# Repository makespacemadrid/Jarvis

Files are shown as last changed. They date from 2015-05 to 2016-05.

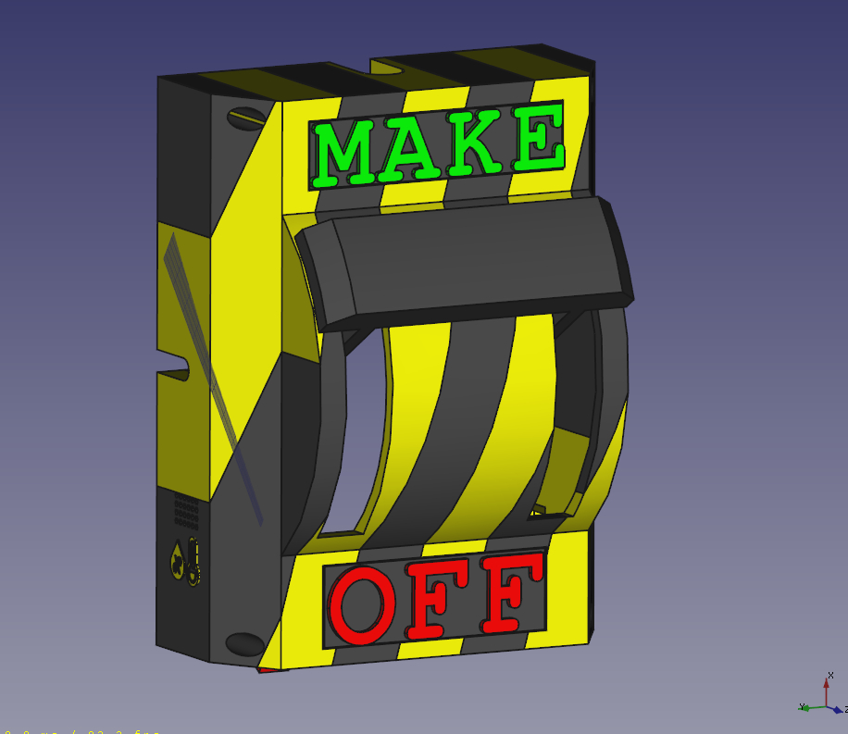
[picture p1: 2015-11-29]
Diseños3D/MakeSwitch/v2.jpg

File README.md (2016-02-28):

# Jarvis
Jarvis (En homenaje al personaje de Marvel) es un proyecto creado por los usuarios de Makespace Madrid para domotizar y automatizar distintos aspectos de dicho espacio.

Se basa en un diseño modular que permite hacerlo escalable, de forma que inicialmente será un diseño simple destinado a realizar tareas rutinarias y monótonas del local (apagado de luces, apagado de ordenadores, control y monitorización de la calidad del aire...) y poco a poco podrá ampliarse a tareas cada vez más sofisticadas y complejas.

Pese a estar siendo desarrollado para un lugar concreto es fácilmente portable a otro tipo de ambientes (locales de trabajo, viviendas... )

****Cómo colaborar:****

1- Haz un fork del repo y aprende a usar git a nivel basico:

    https://github.com/makespacemadrid/Jarvis/wiki/Git-b%C3%A1sico

2- Monta el entorno de desarollo

    https://github.com/makespacemadrid/Jarvis/wiki/Montando-el-entorno-de-desarrollo

3- Si en el camino encuentras algo que falta o esta mal explicado mejoralo en la wiki para el proximo ;)

4-Echa un ojo a los issues y encuentra alguna tarea con la que te gustaria colaborar:

    https://github.com/makespacemadrid/Jarvis/issues

5-Pásate por MakeSpace y habla con un miembro del equipo de Jarvis para tutela/materiales, el Jueves suele ser un dia propicio.

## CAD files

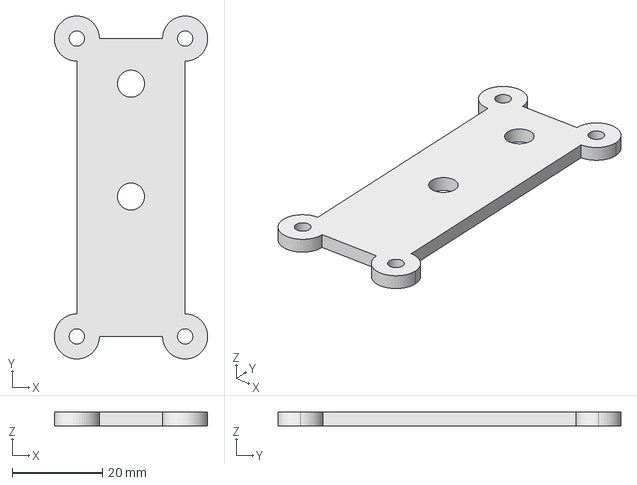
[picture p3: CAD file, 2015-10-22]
Diseños3D/CalidadAmbiental/FreeCAD/tapa_modulo.fcstd
34.0 x 76.0 x 3.00 mm

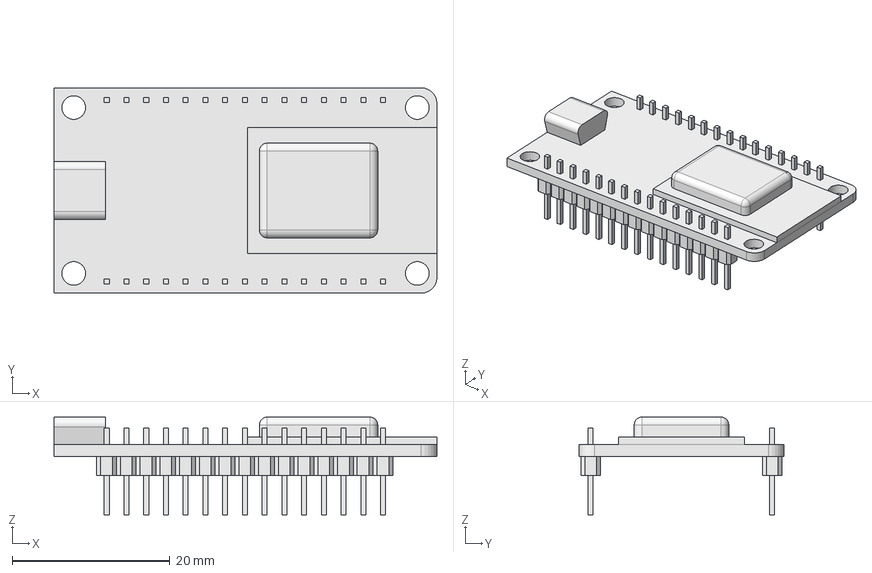
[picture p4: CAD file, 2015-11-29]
Diseños3D/esp/nodemcu.fcstd
48.5 x 26.0 x 12.4 mm
Sketch001_Extrude
NodeMCU-Compound
NodeMCU

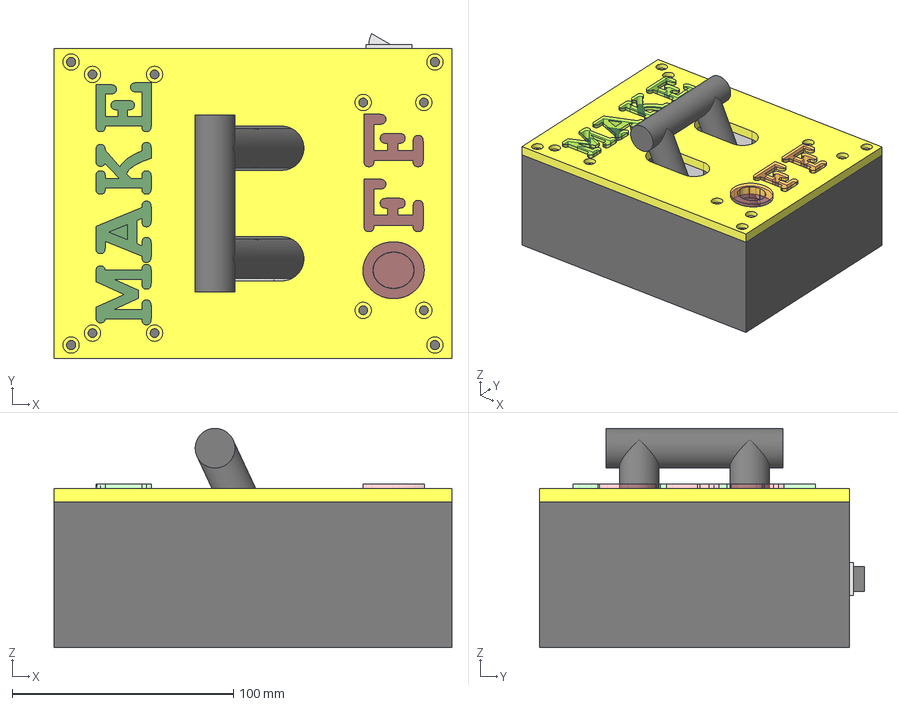
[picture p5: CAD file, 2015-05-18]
Diseños3D/MakeSwitch/FreeCad/MakeSwitch.fcstd
180.0 x 146.8 x 99.2 mm
Clone of Pad002
Clone of Pad001
Clone of Cut003
Facebinder
Interruptor003

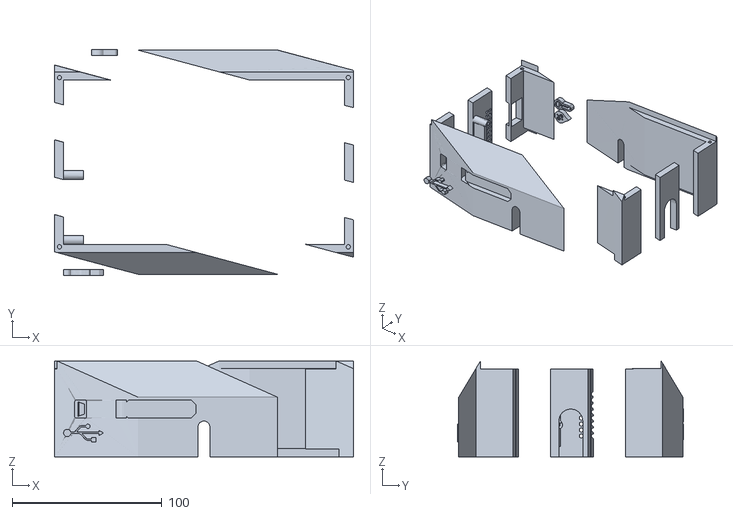
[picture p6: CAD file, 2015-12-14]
Diseños3D/MakeSwitch/FreeCad/STL/DualColor/carcasa-mitades/bottom-a (repaired).stl
200.0 x 151.3 x 64.2

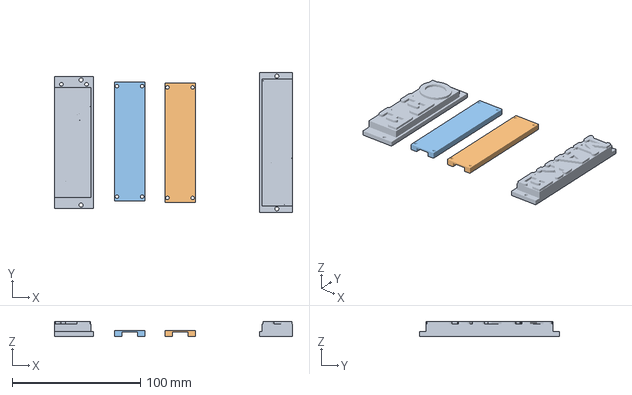
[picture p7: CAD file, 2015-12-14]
Diseños3D/MakeSwitch/FreeCad/STL/DualColor/letras-OpacoA-TransparenteB.amf
185.4 x 108.9 x 12.0 mm

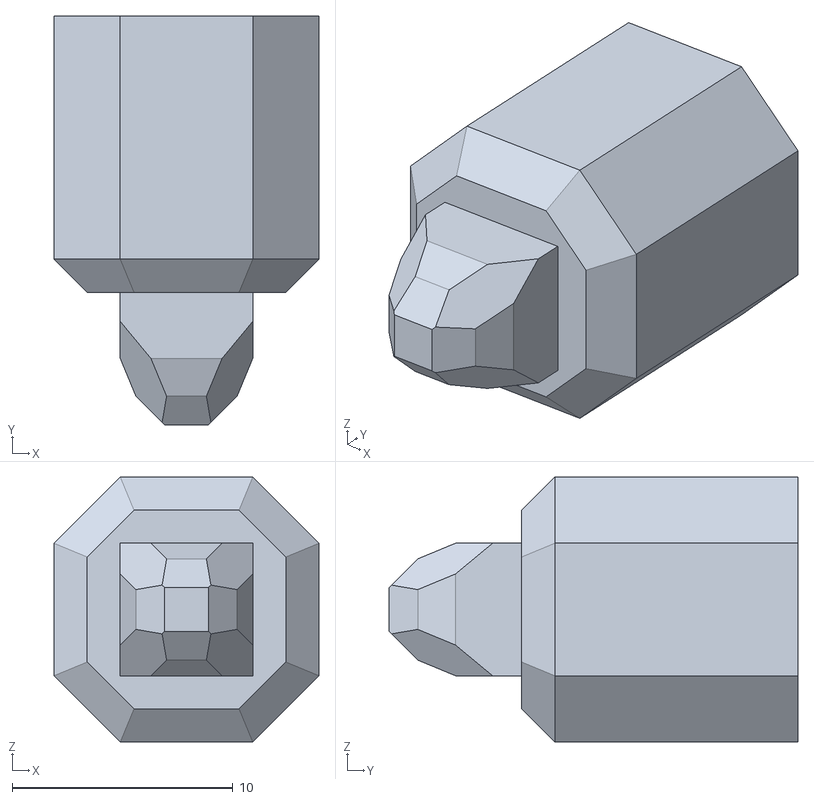
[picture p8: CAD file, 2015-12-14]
Diseños3D/MakeSwitch/FreeCad/STL/piloto.obj
12.0 x 18.5 x 12.0

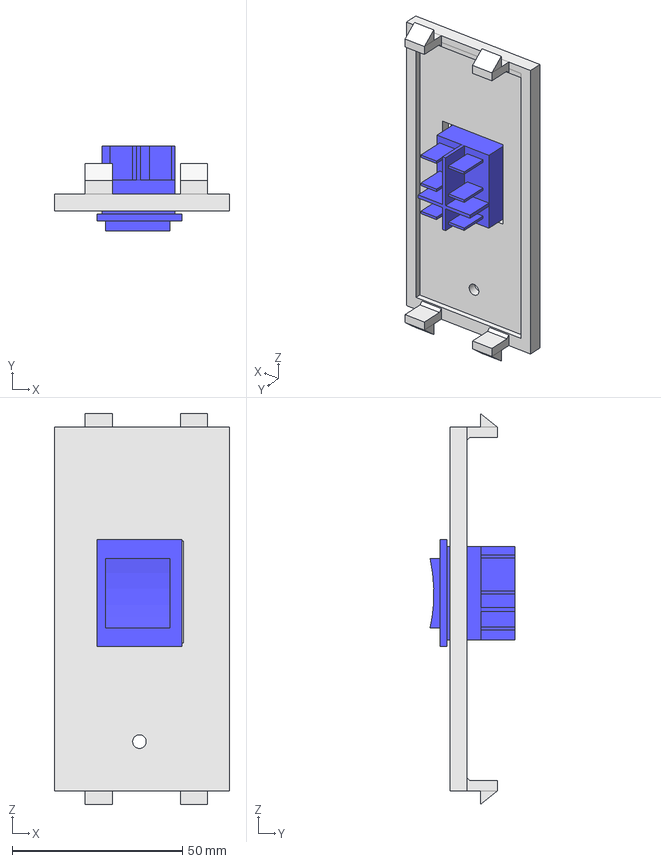
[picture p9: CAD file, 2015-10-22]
Diseños3D/Modulo para CimaBox/FreeCAD/cubre-modulos.fcstd
51.5 x 25.0 x 115.0 mm
Clone conmutador

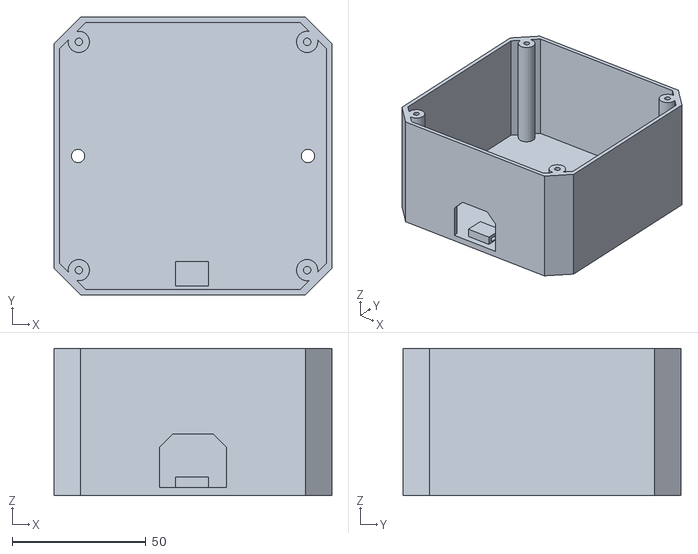
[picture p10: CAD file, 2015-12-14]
Modulos/ZonaHerramientas/caja.stl
104.0 x 104.0 x 55.0

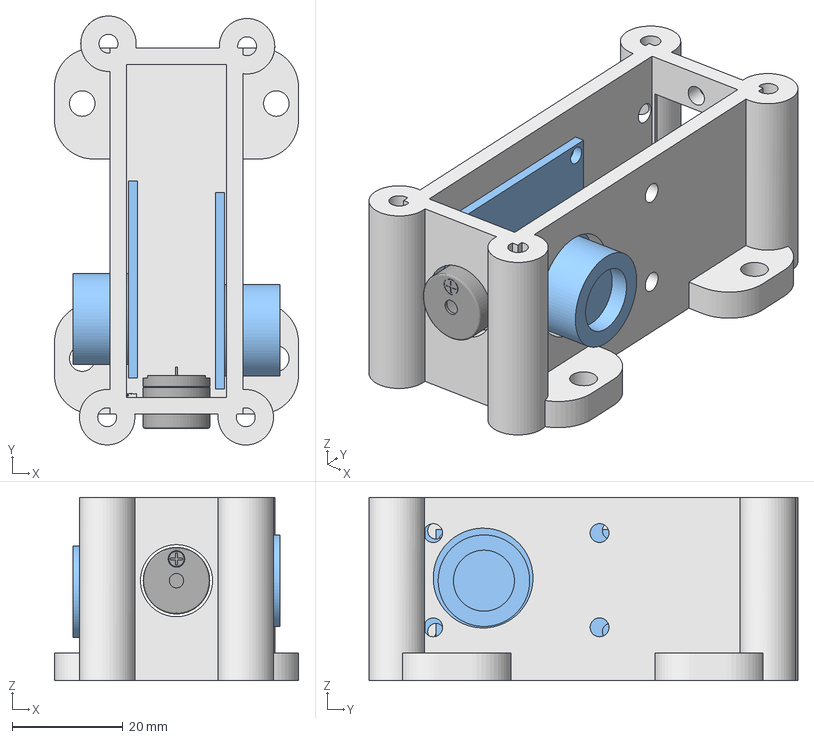
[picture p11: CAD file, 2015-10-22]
Diseños3D/CalidadAmbiental/FreeCAD/carcasa_modulo.fcstd
44.0 x 77.4 x 33.0 mm
Arduino_Pro_Nano_or_Mini_USB
gas_sensor
Buzzer
gas_sensor001

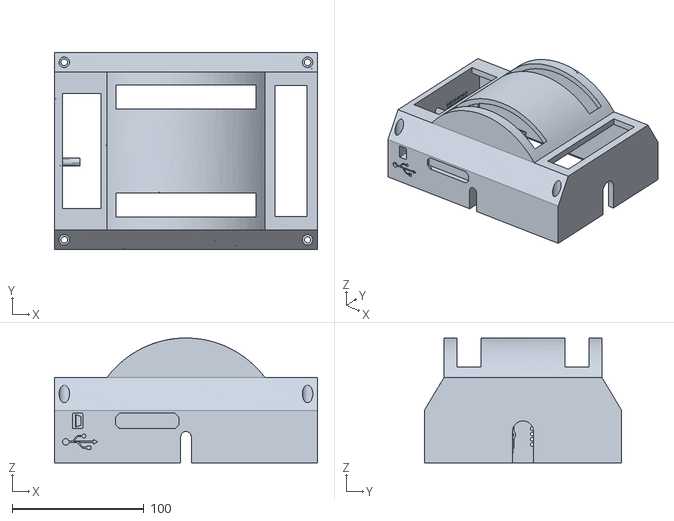
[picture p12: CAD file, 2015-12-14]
Diseños3D/MakeSwitch/FreeCad/STL/carcasa-sinlgeColor (repaired).stl
200.0 x 150.0 x 94.9

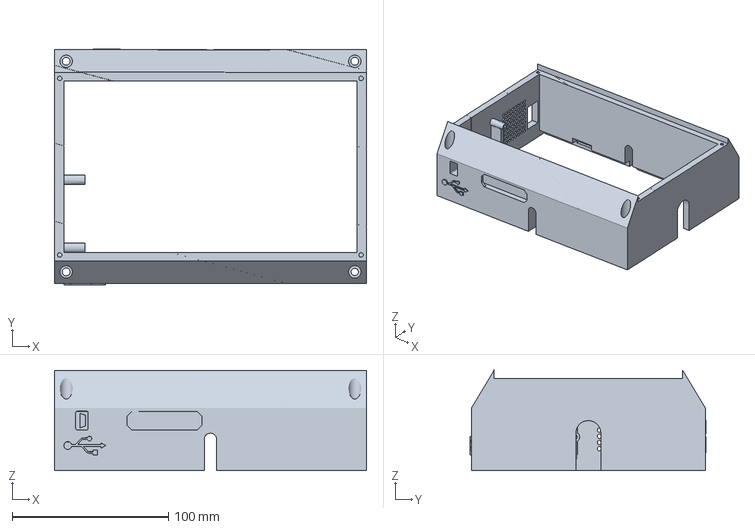
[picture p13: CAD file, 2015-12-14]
Diseños3D/MakeSwitch/FreeCad/STL/DualColor/carcasa-mitades/bottom.amf
200.0 x 151.3 x 64.3 mm

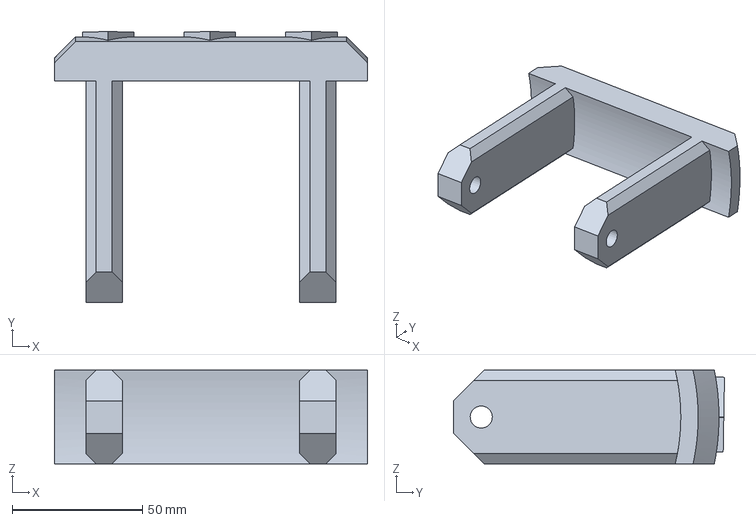
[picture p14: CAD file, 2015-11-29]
Diseños3D/MakeSwitch/FreeCad/STL/DualColor/palanca-flechas-secundario.amf
120.0 x 103.9 x 36.0 mm

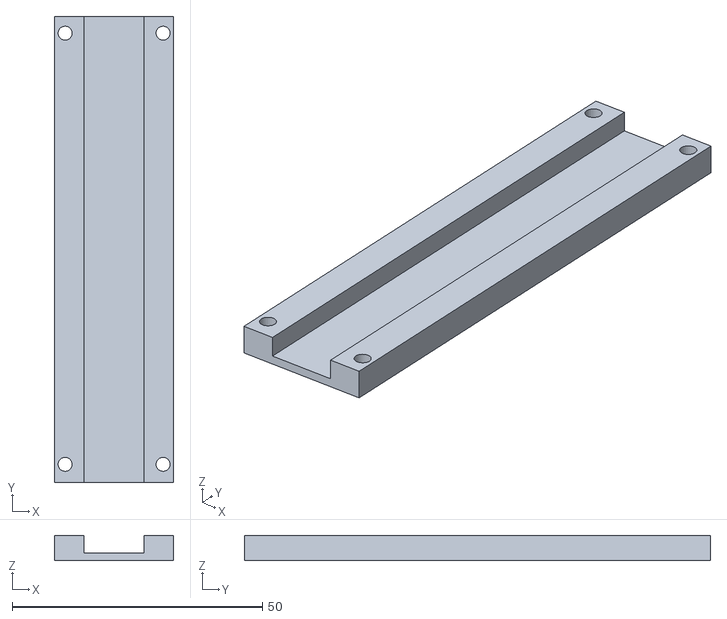
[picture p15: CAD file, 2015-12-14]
Diseños3D/MakeSwitch/FreeCad/STL/cierre_leds.obj
23.8 x 93.0 x 5.00

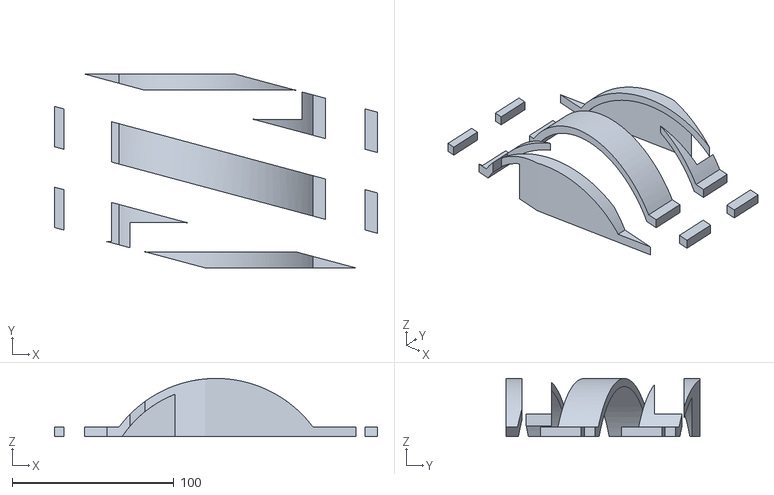
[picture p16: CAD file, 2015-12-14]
Diseños3D/MakeSwitch/FreeCad/STL/DualColor/carcasa-mitades/top-b.obj
200.0 x 120.0 x 36.0

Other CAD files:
Diseños3D/CalidadAmbiental/stl/tapa_carcasa.stl
Modulos/ZonaHerramientas/protecciones-mesaHerramientas.fcstd
Diseños3D/MakeSwitch/FreeCad/STL/DualColor/carcasa-dual.amf
Diseños3D/MakeSwitch/FreeCad/STL/DualColor/carcasa-mitades/bottom-a.obj
Diseños3D/CalidadAmbiental/stl/carcasa_modulo.stl
Diseños3D/MakeSwitch/FreeCad/STL/DualColor/carcasa-mitades/bottom-b (repaired).stl
Diseños3D/MakeSwitch/FreeCad/STL/DualColor/carcasa-mitades/bottom-b.obj
Diseños3D/MakeSwitch/FreeCad/STL/DualColor/carcasa-mitades/top-a.obj
Diseños3D/MakeSwitch/FreeCad/STL/DualColor/carcasa-mitades/top.amf
Diseños3D/MakeSwitch/FreeCad/STL/DualColor/carcasa_make-amarillo (repaired).stl
Diseños3D/MakeSwitch/FreeCad/STL/DualColor/carcasa_make-negro (repaired).stl
Diseños3D/MakeSwitch/FreeCad/STL/DualColor/letras-opaco.obj
Diseños3D/MakeSwitch/FreeCad/STL/DualColor/letras-transparente.obj
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

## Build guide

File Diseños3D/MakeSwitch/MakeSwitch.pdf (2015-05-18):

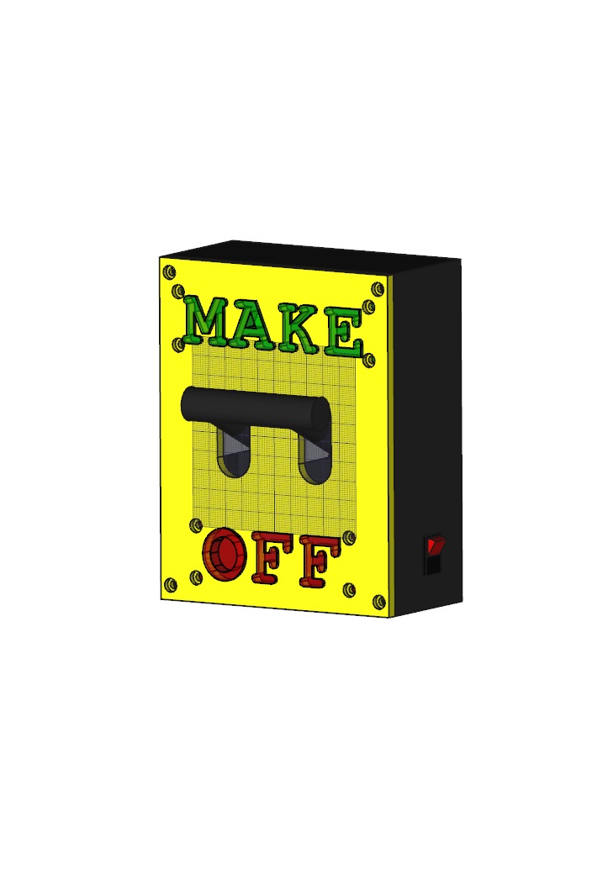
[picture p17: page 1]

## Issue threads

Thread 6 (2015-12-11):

Arduino Nano casi sin memoria

darkjavi, 2015-12-11:
El firmware esta ya tochete y apenas entra en el arduino Nano (99% en este momento).

He creado un par de etiquetas para ir poniendo por el codigo y arañar algunos bites aquí y allá.

#define VERBOSE_DEBUG
    Serial.println("Literales de texto que comen mazo de memoria")
#endif

#define BIG_FLASH
  void funcionQueIgualNoHaceFaltaEnElNano()
      {
          blabla();
      }
#endif

A parte de eso se puede ganar bastante memoria cambiando las cadenas del protocolo por algo menos descriptivo y mas corto p.e. wifistatus - > ws, ahí si que creo que hay un montón de bytes que se pueden sacar.

darkjavi, 2015-12-20:
Otra idea para resolverlo pordria ser desactivar la eeprom(4K) en el Nano, dejando todos los settings en el esp y proveyendo de mecanismos para recuperar los settings.

trastejant, 2015-12-20:
Tambien podemos almacenar algunos parametros de configuracion en la SD.

Closed 2016-05-04.

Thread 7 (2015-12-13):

esp 8266 reset cause:4, boot mode:(1,6)

darkjavi, 2015-12-13:
El esp se reinicia por el watchdog de vez en cuando y se queda colgado.

Investigar estos temas:
https://github.com/esp8266/Arduino/issues/244
https://github.com/esp8266/Arduino/issues/1013

No lo he mirado en profundidad, pero podría ser que un microfallo en la alimentación haga que se cuelgue el micro y al reiniciarse no levanta bien porque se están usando algunos de los gpios(0,2) que se usan para poner el modo bootloader.

darkjavi, 2016-03-11:
Al actualizar la versión 2.1 ha mejorado mucho la estabilidad de los módulos y ya no se reinician tan frecuentemente, aunque todavía se quedan bloqueados de cuando en cuando.

Closed 2016-03-11.

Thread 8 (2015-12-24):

insuficiente gas vespeno!

darkjavi, 2015-12-24:

trastejant, 2015-12-24:
VCE preparado para partir, señor.

darkjavi, 2015-12-24:
Depósitos extra de suministros requeridos! ;)

trastejant, 2015-12-25:
¡Dame algo a lo qué disparar !

darkjavi, 2015-12-28:
Vamos, vamos, vamos!!!!

trastejant, 2015-12-31:
¿Quieres fuego?

darkjavi, 2016-01-03:
¿Ha llamado alguien a un exterminador?

balrog-kun, 2016-01-03:
Parece que Necesitamos Mas Pilones!

darkjavi, 2016-01-04:
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
Mi vida por Aiur!

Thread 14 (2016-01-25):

Hay que configurar el Travis

darkjavi, 2016-01-25:
Travis prueba todos los pull request que se abren compilandolos/ejecutando pruebas pre programadas.

Lo he registrado pero no esta configurado,  Marlin lo tiene montado e igual su fichero de config sirve para ver como va:
https://github.com/MarlinFirmware/Marlin/blob/RC/.travis.yml

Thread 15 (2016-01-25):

Pagina web de configuración del nodo

darkjavi, 2016-01-25:

darkjavi, 2016-02-25:
Parámetros mas prioritarios para la pagina web:

ID del nodo
Tipo de nodo
Esssid      wifi
password wifi
Ip del server (aka Jarvis)
Puerto del server

mr3188, 2016-12-27:
Tengo el formulario hecho en espWebServer pero estoy buscando el mejor sitio para meterlo y tener acceso a la configuración.

darkjavi, 2016-12-27:
Genial Miguel!
Pues a ver si encontramos un ratito que coincidamos en mks y vemos como integrar el codigo que tienes en el repo

trastejant, 2016-12-30:
Si! Proposito de año nuevo! que no se nos escape enero sin reunirnos para organizar Jarvis! ;-)

mr3188, 2017-05-25:
A la hora de mostrar en tipo de nodo en el formulario web de configuración me encuentro con un problema. La lista de tipos de nodos definida en settings.h es un enum, ¿de donde puedo sacar un array con los nombres de cada uno y que esté siempre sincronizada con el enum? ¿creo un array estático de nombres en el mismo fichero de cabecera?

darkjavi, 2017-05-27:
Me he visto varias veces en el mismo problema y nunca he dado con una solución sencilla para enumerar un enum y sacar los nombres de de cada uno de los elementos de manera totalmente automática, pues el enum al final son etiquetas que representan un valor entero(0,1,2...)

Creo que lo más sencillo es lo que dices,  meter una función en el settings.h que devuelva un array con los nombres en el mismo orden en el que están en el enum, y cuando se añade un nuevo tipo de nodo en el settings se añade también a esa función. Como están en el mismo orden la posicion en el array coincide con el indice del enum que representa.

Algo en plan...
```C
static std::vector<String> getNodeTypes()
{
  std::vector<String> nodeTypes;
  nodeTypes << "unknownModule" << "unConfiguredModule" << "simpleSwitchModule" << "etc etc"

  return nodeTypes
}
```

Asi desde otras partes del código puedes obtener la lista de nodos con su nombre en String, y  a la hora de meter más solo hay que añadirlos en esa función.

balrog-kun, 2017-05-28:
No es que haga diferencia notable pero un array estatico tiene la ventaja de que lo generas solo una vez y tienes solo una copia.  Y si es un array del tipo C antiguo se puede definir de manera independiente del orden de los enums:

const char *nodeType[] = {
    [unknownModule] = "unknownModule",
    etc,
};

O con un switch () en una funcion.  Tambien hay truquitos feos del C para no escribir lo mismo mas de una vez pero no se usan en practica ([en sensorino si](https://github.com/Sensorino/Sensorino/blob/master/Sensorino/Message.h#L12)), y por lo visto hay truquitos nuevos en las ultimas versiones de C++.

darkjavi, 2017-05-28:
Si, en efecto hacerlo con array estático ahorra unos bytes de memoria. Igual es una cosa personal de que le tengo bastante tirria a los arrays estáticos de C y prefiero gastar unos bytes para tener métodos de alto nivel  p.e.  .count() para poder poder iterar cómodamente.

//array dinamico
for(int i = 0 ; i < array.count() ; i++)

//array estatico
for(int i = 0 ; i < (sizeof(array)/sizeof(tipoDeDato))) ; i++)

También creo que la primera forma es mas fácil de entender para los newbies

balrog-kun, 2017-05-29:
Si, ya que usamos C++ es buena idea aprovecharlo.  Aun asi el vector puede ser estatico para no re-generarlo todas las veces que se llama la funcion y devolver referenca haria que el que llama no pierda tiempo volviendo a copiarlo implicitamente.  Tambien debe poderse hacer de manera que no dependa del orden de los enums (parece que desde C++11 han hecho mas facil inicializar un std::vector, en versiones anteriores es a base de un array C o dinamicamente `nodeType[unknownModule] = "unknownModule";`).  Son detalles pero ya que estams comentando preferencias..

Respecto a los bucles en los proyectos que hay se ve que el enum al final tiene un valor adicional que puedes usar de tope para los bucles,
```
enum nodeTypes {
   unknownModule,
   ...,

   __maxNodeType
};
```
Si es solo un array de strings algunas veces se añade un NULL para poder iterar con `for (auto i = array; i; i++) ...` sin los sizeof.

mr3188, 2017-05-30:
Lo estoy haciendo con un vector estático que en C++11 se puede inicializar igual que un array.

El número de valores del emun se calcula como dice Andrew con el último elemento del enum, el número de elementos del vector se puede calcular de un modo algo menos fino con __LINE__ . Al final, se genera un error de compilación con static_assert si los dos números no coinciden, mejor detectar errores en compilación que en tiempo de ejecución.

Ahora lo compilaré en el ESP para ver si funciona todo.

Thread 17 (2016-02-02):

[SW]Manejo coherente de los settings

darkjavi, 2016-02-02:
Darle coherencia al esquema de los settings guardados en EEPROM.
Ahora mismo los objetos están creados, pero falta terminar de dar con el esquema con el que se van a salvar así como reemplazar en sitios varios configuración puesta 'a pelo' por los settings que vienen de la eeprom.

Closed 2016-03-20.

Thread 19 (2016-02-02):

Implementacion del sensor de consumo.

darkjavi, 2016-02-02:
Hay sondas amperimetricas para implementar, hay varias formulas molonas para medir el consumo aunque ahora lo mas importante es adaptar el 'hardware'; La sonda escupe de -1V a +1V, hay que adaptarlo para poder leerlo con una patilla analógica de 0-3.3V.

mr3188, 2016-06-06:
¿ que hardware se ha decidido para los sensores de corriente?  ¿te refieres a los sensores no invasivos tipo SCT-013-30 ?

darkjavi, 2016-06-07:
Si,de hecho son esos mismos!! :)

Escupen de -1V a +1V con el consumo de -30A a +30A. Creo que de precisión no van a estar muy bien, pero valdrá para calcular el consumo mas o menos.

mr3188, 2016-06-07:
Hace falta espacio en una placa para poner un par de resistencias para elevar la señal y un jack que suelen llevar esos sensores. Yo esos sensores los uso para comprobar si el aparato en cuestión está encendido o apagado sin molestarme en calcular el consumo pero en OpenEnergyMonitor usan una fuente AC/AC para hacer el calculo real de consumo ¿necesitamos el kit completo o solo detectar si hay corriente?
¿hacemos una placa para conectar varios sensores o conectamos de forma individual cada sensor al micro?

darkjavi, 2016-06-09:
En principio las pinzas amperimetricas son para instalarlas en los módulos que controlaran los enchufes, una por modulo para estimar el consumo electrico.Tambien hay una instalada en la cafetera Jarvis.

Sobre el kit de OpenEnergy habría que ver lo que cuesta el kit de hardware y valorar que mejoras nos da.

Si te animas con el circuito para leer la sonda adelante!

mr3188, 2016-06-09:
ok, Yo tengo ya hecha alguna placa para ese sensor, voy a recuperarla e
intento conectarla con Jarvis.
Con lo del kit no me refería al kit de OpenEnergyMoitor, me refería a si
teníamos que unirlo con  el transformador AC/AC, reducir el voltaje del
trafo a 3.3, medir el desfase, etc. Pero por el momento retomo lo que ya
tenía, subo la señal de la sonda y se la mando al micro.

El 9 de junio de 2016, 11:38, darkjavi <notifications@github.com> escribió:

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

darkjavi, 2017-03-13:
Como van esas implementaciones.. no veo pull request todavia xD
Buscamos un día para vernos en mks y verlo?

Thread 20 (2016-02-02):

Gestor de reglas en los nodos

darkjavi, 2016-02-02:
A parte de los nodos predefinidos, cuya funcionalidad viene predefinida de serie estaría bien tener un mecanismo de añadir reglas dinamicamente a los nodos. También seria interesante un tipo de nodo genérico al que se le pueden añadir componentes de forma dinámica.

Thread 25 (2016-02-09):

[SW]ESP8266 FOTA

darkjavi, 2016-02-09:
En las ultimas versiones de la integración con arduino han añadido un actualizador web, esta un poco verde pero ya funciona.

Sin perjuicio de mejores/futuras formas de actualización se ha integrado en el firmware junto con un respondedor mdns y esta accesible a través de la dirección:
http://<**nodeId**>/update

Closed 2016-02-28.

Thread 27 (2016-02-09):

[HW/SW]Watchdog por hardware

darkjavi, 2016-02-09:
En relacion a #7.

La estabilidad del firmware ha mejorado muchísimo con las ultimas versiones de la integración con arduino, especialmente la ultima versión de desarrollo (2.1-rc2). Aun así se quedan pegados alguna vez y seria muy útil tener un reset por hardware;
Algún tipo de circuito de condensadores/resistencias que si no recibe una pulsación periódica de una patilla del esp le de una pulsación al reset del micro.
¿Ideas?

darkjavi, 2016-03-17:
Mirar la posibilidad de instalar un pequeño microcontrolador para hacer de perro guardian:
http://www.electronicaembajadores.com/Productos/Detalle/-1/SMCIATTINY85/microcontrolador-attiny85-20pu

trastejant, 2016-05-28:
Igual complicamos -y encarecemos- los modulos, pero según lo veo simplemente necesitamos enviar a un alive a este chip cada n X ms, el alive reinicia el contador del tiny. Si no recibimos un alive el tiny levanta el reset del ESP.

Seguro que esto tiene alguna pega que ahora mismo se me escapa... Pero se puede intentar. ¿Tenemos quemadores en el espacio para este chip?

darkjavi, 2016-05-28:
Hay ya una primera implementacion super sencilla, el esp conectado a una patilla de un nano, cambiando el estado de una patilla cada 5 segundos.
Si la patilla no cambia de estado en 20 segundos el Nano le pega un reset al esp.
Ese mismo nano podría ser el que lee sensores por i2c.

Si quieres echarle un ojo esta en la carpeta watchdog firmware del repo :)

trastejant, 2016-05-28:
Tengo que mirarme todo el código... ya tengo un ordenador decente XD

Closed 2016-03-20.

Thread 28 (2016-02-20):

El compilador no encuentra <vector>

gmag11, 2016-02-20:
Al intentar compilar sale el error:

`communication.h:In file included from`
`jarvisNode.h:from`
`JarvisFirmware.ino:from`
`jarvisParser.h:7:18: fatal error: vector: No such file or directory`
`:#include <vector>`
`:compilation terminated`
`Error compiling project sources`

He añadido la librería StandardCplusplus de tu repositorio con el entorno de Arduino.

Estoy usando el entorno Arduino ESP descargado directamente desde GitHub y un ESP12 de 4 MB

darkjavi, 2016-02-21:
Como estas compilando?
Me suena a que se esta intentando compilar para arduino en vez de para el ESP, la clase vector va de serie en complemento que se le mete al arduino para hacer código para el ESP y la librería la tenia para dar la compatibilidad con arduinos.

Closed 2016-05-04.

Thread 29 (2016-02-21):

'Hackear' el backend de leds para optimizar la memoria

darkjavi, 2016-02-21:
Se esta usando la librería de adafruit para manejar los ws2812, y creo que se esta gastando bastante memoria con los arrays de valores para los leds.

Hay un array en en objeto ws2812Strip que contiene las ternas rgb para la tira, y sospecho que la librería de adafruit también esta guardando su propio array de valores para gestionar la tira.

Investigar si esto es así e intentar modificar la librería para que tire desde el array externo para liberar memoria. También se puede mirar la librería FastLed para manejar los ws2812, que no se si funcionara de la misma manera.

En general esto no presenta un problema salvo para el nodo de panel de leds, que tiene 300 leds(300 leds * 3 bytes = 900b) y en algunas operaciones esta crujiendo por(sospecho) falta de memoria ram.

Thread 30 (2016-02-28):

[Nodo] CoffeeMaker

darkjavi, 2016-02-28:
Propósito del nodo:
  -Asegurar que la cafetera se desconecta cuando no se usa.
  -Re programar la lógica casi inexistente con la que la electrónica hace café por un programa temporizado, ej.: Pulsas el botón y la cafetera se calienta y activa la bomba de agua por 30 segundos(tipo ne$$preso).

Detalles de implementacion:
Basado en el nodo simplePowerControl, que es para controlar un rele con un botón para encender y apagar el rele. Añade luces led para señalizar y un rele extra para activar la bomba de agua de la cafetera.

Estado:
HW: 70%
SW: 70%

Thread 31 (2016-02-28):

[Nodo] ledPanelNode

darkjavi, 2016-02-28:
**Propósito del nodo:**
  -Iluminación de la entrada de MakeSpace, con efectos de luz y color.
  -Proyección de caracteres y textos.

**Detalles de implementación:**
  -

**Estado**:
HW: 70%
SW: 70%

Numero de nodos necesarios: 1 , Construidos 1(alpha).

darkjavi, 2016-05-04:
Instalado y funcionando, aunque todavía tiene un par de bugs que hay que mirar

Closed 2016-05-04.

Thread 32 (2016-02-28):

[Nodo] Calidad del aire

darkjavi, 2016-02-28:
**Propósito del nodo:**
  -Medir diferentes aspectos de la calidad del aire en el espacio.
  -Sensor de llama para alarma de incendio.

**Detalles de implementación:**
  -

**Estado**:
HW: -%
SW: -%

Numero de nodos necesarios: - , Construidos -.

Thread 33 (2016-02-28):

[Nodo] Control de la iluminación

darkjavi, 2016-02-28:
**Propósito del nodo:**
  -Encender y apagar las luces de las diferentes zonas de MakeSpace.
  -Aparte de un botón para encender y apagar por 'software' debe de tener un mecanismo manual para activar la luz en caso de fallo del sistema.

**Detalles de implementación:**
  -Basado en el nodo simplePowerControl, que es para controlar un rele con un botón para encender y apagar el rele.

**Estado**:
HW: 0%
SW: 60%

Numero de nodos necesarios: ~6 , Construidos 0

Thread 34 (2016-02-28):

[Nodo] Control de enchufes

darkjavi, 2016-02-28:
**Propósito del nodo:**
  -Activar y desactivar las regletas de las zonas de MakeSpace.
  -Medición de consumo con sonda amperimetrica.
  -Auto-apagado en caso de sobrecalentamiento / sobreconsumo
  -Posibilidad de hacer dimmer con rele de estado solido.
  -Mecanismo manual de activación en caso de fallo del sistema.

 -Se presenta en dos formatos fisicos; como caja para poner en serie con una regleta para controlarla y como modulo para meter dentro de las cajas c.i.m.a que hay en el espacio

**Detalles de implementación:**
  -Basado en el nodo advancedPowerControl, que es para controlar un rele de estado solido

**Estado**:
HW: 0%
SW: 60%

Numero de nodos necesarios: ~8 , Construidos 0.

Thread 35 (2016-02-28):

[Nodo] Control de acceso

darkjavi, 2016-02-28:
**Propósito del nodo:**
  -Controlar la cerradura de la puerta interior del espacio.
  -Botón para activar un timbre para que los visitantes puedan llamar.
  -Pin-pad que te abre la puerta al marcar el código correcto.

**Detalles de implementación:**
-Personalmente creo que es mejor utilizar una cerradura de las que abren cuando aplicas corriente, mejor que el modulo de cierre magnético que tenemos. De ese modulo lo que si podríamos usar es el sensor de cierre para saber cuando se ha cerrado la puerta

**Estado**:
HW: 0%
SW: 0%

Numero de nodos necesarios: 1 , Construidos 0.

trastejant, 2016-05-28:
¿Novedades en este tema? propongo añadir la tarjeta con la que abrimos el cierre como opción complementaria al pin-pad. Es fácil de implementar y es única, a diferencia del pin, lo que facilita el control de acceso.

darkjavi, 2016-05-28:
Manuel esta trabajando en este modulo, en una primera versión que este conectada a la apertura eléctrica de la puerta que hemos instalado en el ultimo mes.

Para la V2 un pin pad, y para la V3 habria que ver si se puede integrar esto (http://hackaday.com/2016/04/13/carontepass-open-access-control-for-your-hackerspace/) en el firmware de Jarvis

trastejant, 2016-05-28:
Exacto, eso es justo lo que tenia en mente. Ahora precisamente estoy cacharreando con esos módulos para un robot que estoy diseñando, así que puedo aportar en ello.

darkjavi, 2017-03-13:
En esta semana he estado trabajando en el nfc del espacio.
He actualizado a versión 2 el abre puertas exterior(el de la persiana), de momento no está conectado a Jarvis.

Habia un par de rc522 por ahí sueltos y he instalado uno en el modulo abre puerta interior para probarlo, de momento tirando del mismo array de autorización que la puerta exterior.

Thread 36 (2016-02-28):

[Nodo] MakeSwitch

darkjavi, 2016-02-28:
**Propósito del nodo:**
  -Desencadenar el encendido / apagado global del espacio.
  -Feedback visual / sonoro.
  -Contador de 5 segundos para cambiar de opinión.

**Detalles de implementación:**
  -Basado en el nodo simpleSwitch, que es gestiona un pulsador, añade la funcionalidad de los leds de feedback.

**Estado**:
HW: 90%
SW: 90%

Numero de nodos necesarios: 1 , Construidos 1(beta).

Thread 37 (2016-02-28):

[Nodo] Consola física de control

darkjavi, 2016-02-28:
**Propósito del nodo:**
  -Sin perjuicio de otros métodos de interfaz/control un buen panel lleno de botones, diales y luces seria bastante útil / Visualmente satisfactorio. Puede que este sea el objeto en el que resida Jarvis físicamente(la raspberry).
  - Los botones/luces pueden mapearse para activar/señalizar cualquiera de los nodos.

**Detalles de implementación:**
Este nodo puede ser un arduino conectado directamente a la raspberry en la que corre Jarvis, o la raspberry misma si tiene I/Os suficientes.

**Estado**:
HW: 0%
SW: 0%

Numero de nodos necesarios: 1 , Construidos 0.

RndMnkIII, 2016-12-04:
Hola, soy @javivi77, estoy mirando el proyecto, en que consiste y demás. En la parte de la interfaz yo estoy con un proyecto personal parecido pero para la interfaz he pensado en utilizar una pantalla tactil con controlador FT81x incorporado. Presenta las siguientes ventajas:
- En vez de tener una interfaz fisica que habria que modificar, tendria una virtual con tantos controlos como quisieramos y organizado por pestañas por ejemplo.
- Estos controladores con las librerias adecuadas (gameduino2 modificada) son capaces de hacer casi de todo con aceleracion grafica 2D.
- Se pueden controlar con practicamente cualquier uC/placa con soporte SPI.
- Practicamente no necesitan de recursos externos para funcionar (incorpora memoria propia).
- Algunas placas FT81x (la de riverdi la he probado) ofrecen salida amplificada de audio, ya que dicho controlador reproduce sampledsdigitales y archivos midi, x lo que se pueden añadir efectos de sonido a la interfaz.

Dejo algunos enlaces interesantes para que os hagais una idea:
http://gameduino2.proboards.com/attachment/download/109

https://riverdi.com/product-category/displays/ft8xx/

https://forum.arduino.cc/index.php?topic=346755.30

RndMnkIII, 2016-12-04:
http://gameduino2.proboards.com/thread/275/ft810q-gd2-library

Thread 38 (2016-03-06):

[SW] Manejo de los displays de Nokia

darkjavi, 2016-03-06:
Tenemos unos cuantos displays de nokia, hay que implementarlos

trastejant, 2016-05-28:
¡Me lo pido! Para hacerme una idea¿Que idea tenemos para ellos? ¿Que información tienen que mostrar y en que modulos?

darkjavi, 2016-05-28:
Welcome back! ;)

Si quieres vemos un día todas las variables que hay rulando por el firmware para ver cuales son interesantes de llevar al display. De momento se puede ir preparando la inicializacion y sistema básico de pantallas paginadas para los displays.

trastejant, 2016-05-28:
Tengo algunas por casa, en cuanto tenga un ratito.... me pongo con ello. Que ya compilo en tiempos de S XXI

RndMnkIII, 2016-12-05:
Si me podeis pasar modelo de los displays o caracteristicas puedo echar un vistazo sobre como usarlos

trastejant, 2016-12-05:
Hola!
La implementación de las pantallas la tengo bastante avanzada, aun que no la he subido aun...

RndMnkIII, 2016-12-05:
Ok, de todas formas a ver si coincidimos algún día y hablamos de como funciona o que habeis pensado hacer, yo si puedo aportar mi granito de arena pues me gustaria implicarme en un proyecto de este tipo y con gente que le motiva esto.

trastejant, 2016-12-07:
¡Si! A ver cuando podemos organizar una Jarvis-Reunión, tengo ganas de que nos cuentes más  sobre esas  placas FT81x y Gameduino!

darkjavi, 2017-03-13:
Como van esas implementaciones.. no veo pull request todavía xD
Buscamos un dia para vernos en mks y verlo?

trastejant, 2017-03-28:
Tengo unos modulo Jarvis básicos... que están deseosos de ser presentados en sociedad. XD

mr3188, 2017-03-30:
Lo mejor sería quedar un día ¿Cuando os viene bien?

El 29 mar. 2017 1:45 a. m., "Trastejant" <notifications@github.com>
escribió:

Tengo unos modulo Jarvis básicos... que están deseosos de ser presentados
en sociedad. XD

—
You are receiving this because you are subscribed to this thread.
Reply to this email directly, view it on GitHub
<https://github.com/makespacemadrid/Jarvis/issues/38#issuecomment-289938848>,
or mute the thread
<https://github.com/notifications/unsubscribe-auth/AG0W1qphhOSDWJTr3h4xNocN5OAR5JCXks5rqZuugaJpZM4HqVA7>
.

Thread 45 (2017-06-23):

[SW] C++ version

mr3188, 2017-06-23:
Necesitaríamos definir que versión de c++ debemos usar, las últimas versiones de Arduino IDE usan c++11 por defecto pero en mi instalación de Qt está usando una anterior, al compilar algunos ficheros en los dos entornos, soluciones implementadas en Arduino no compilan en Qt.
¿Alguna razón para no usar c++11 por defecto en los dos lados?

Miguel

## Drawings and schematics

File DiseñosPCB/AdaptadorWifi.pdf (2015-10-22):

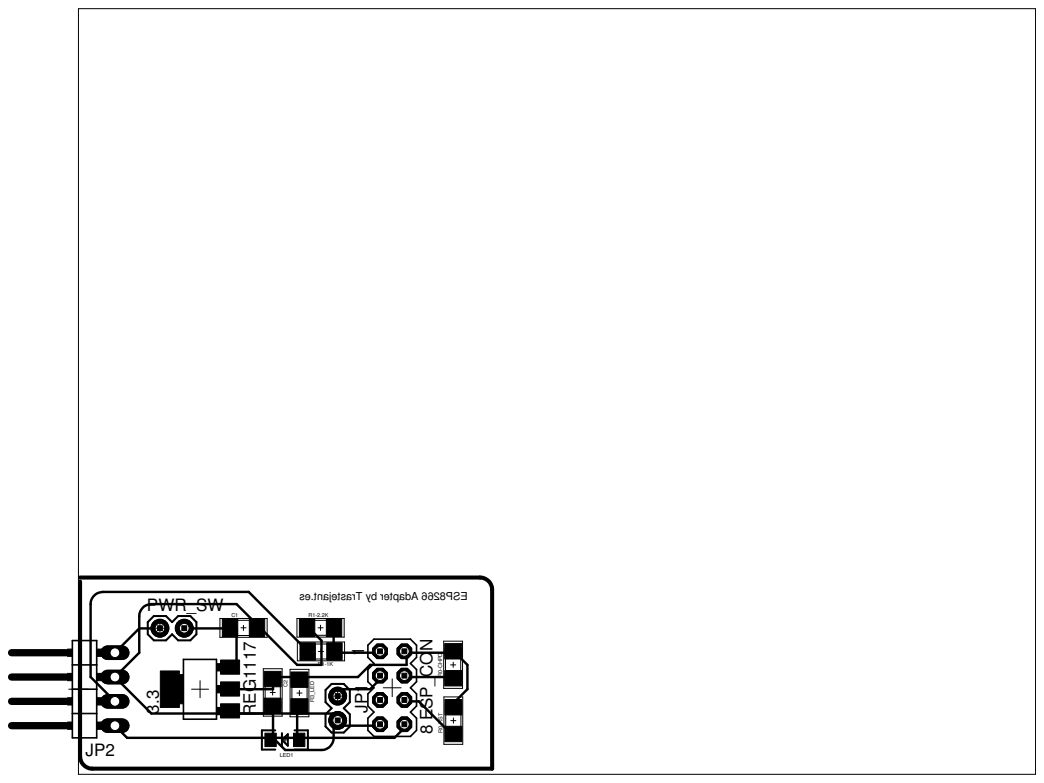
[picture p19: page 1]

se.t naj et sar T ybr et padA 6628PSE 1 8 R0-CHPD ESP_CON 3.3 LED1 R1-2.2K R1-1K JP1R3_LED C1 C2 R0-RST PWR_SW JP2 REG1117

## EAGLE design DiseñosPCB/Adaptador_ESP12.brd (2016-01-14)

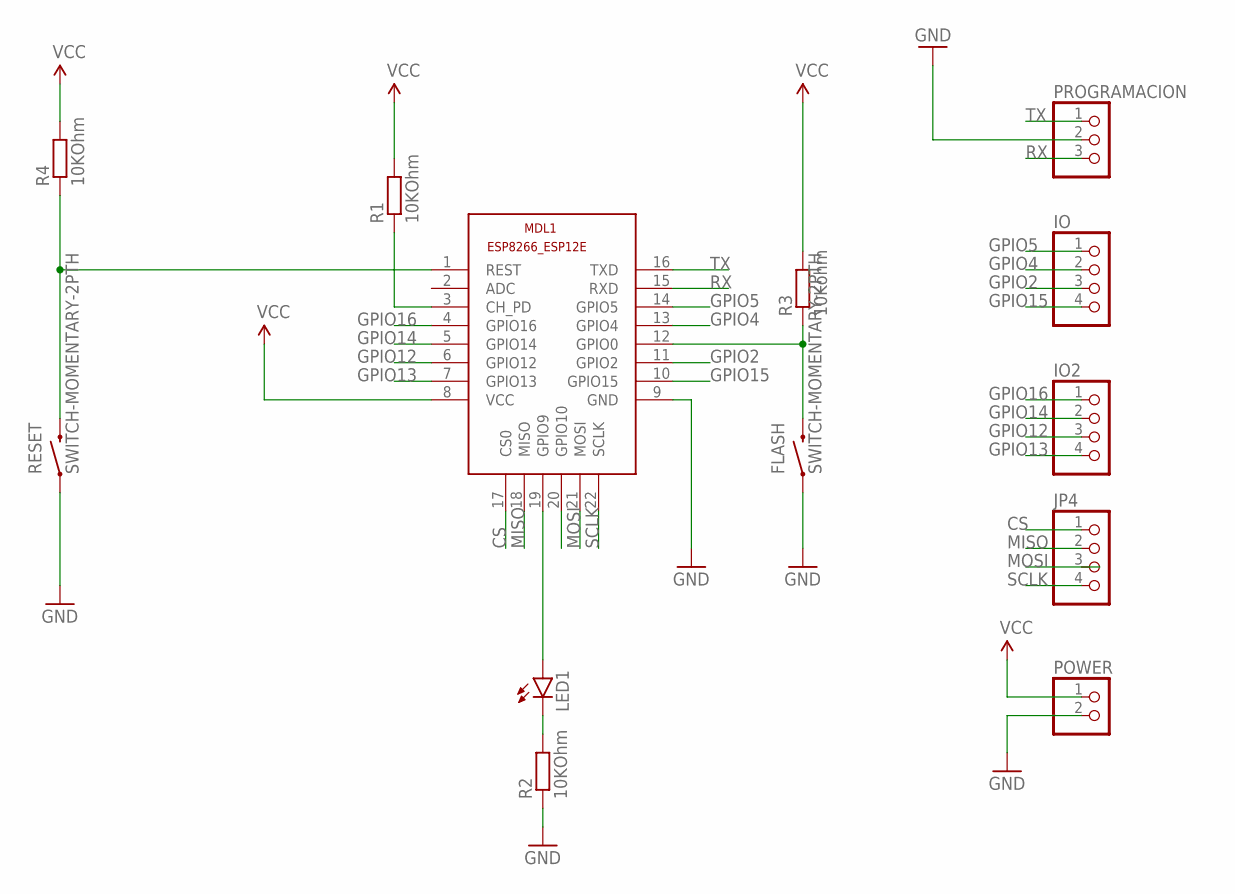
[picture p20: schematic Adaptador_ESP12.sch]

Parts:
FLASH: SWITCH-MOMENTARY-2PTH; TACTILE-PTH
IO, IO2: PINHD-1X4; 1X04
JP4: PINHD-1X4; 1X04
LED1: LED-3MM-NO_SILK; LED3MM-NS
MDL1: ESP8266-12EESP8266-ESP12E; ESP8266-ESP12E
POWER: PINHD-1X2; 1X02
PROGRAMACION: PINHD-1X3; 1X03
R1, R2, R4: 10KOhm; 0207/7
R3: 10Kohm; 0207/7
RESET: SWITCH-MOMENTARY-2PTH; TACTILE-PTH

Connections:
CS: JP4.1, MDL1.17 (CS0)
GND: FLASH.1, MDL1.9 (GND), POWER.2, PROGRAMACION.2, R2.1, RESET.1
GPIO2: IO.3, MDL1.11 (GPIO2)
GPIO4: IO.2, MDL1.13 (GPIO4)
GPIO5: IO.1, MDL1.14 (GPIO5)
GPIO12: IO2.3, MDL1.6 (GPIO12)
GPIO13: IO2.4, MDL1.7 (GPIO13)
GPIO14: IO2.2, MDL1.5 (GPIO14)
GPIO15: IO.4, MDL1.10 (GPIO15)
GPIO16: IO2.1, MDL1.4 (GPIO16)
MISO: JP4.2, MDL1.18 (MISO)
MOSI: MDL1.21 (MOSI)
unnamed: FLASH.3 (2), MDL1.12 (GPIO0), R3.1
unnamed: MDL1.1 (REST), R4.1, RESET.3 (2)
unnamed: MDL1.3 (CH_PD), R1.1
unnamed: LED1.K (C), R2.2
unnamed: LED1.A, MDL1.19 (GPIO9)
RX: MDL1.15 (RXD), PROGRAMACION.3
SCLK: JP4.4, MDL1.22 (SCLK)
TX: MDL1.16 (TXD), PROGRAMACION.1
VCC: MDL1.8 (VCC), POWER.1, R1.2, R3.2, R4.2

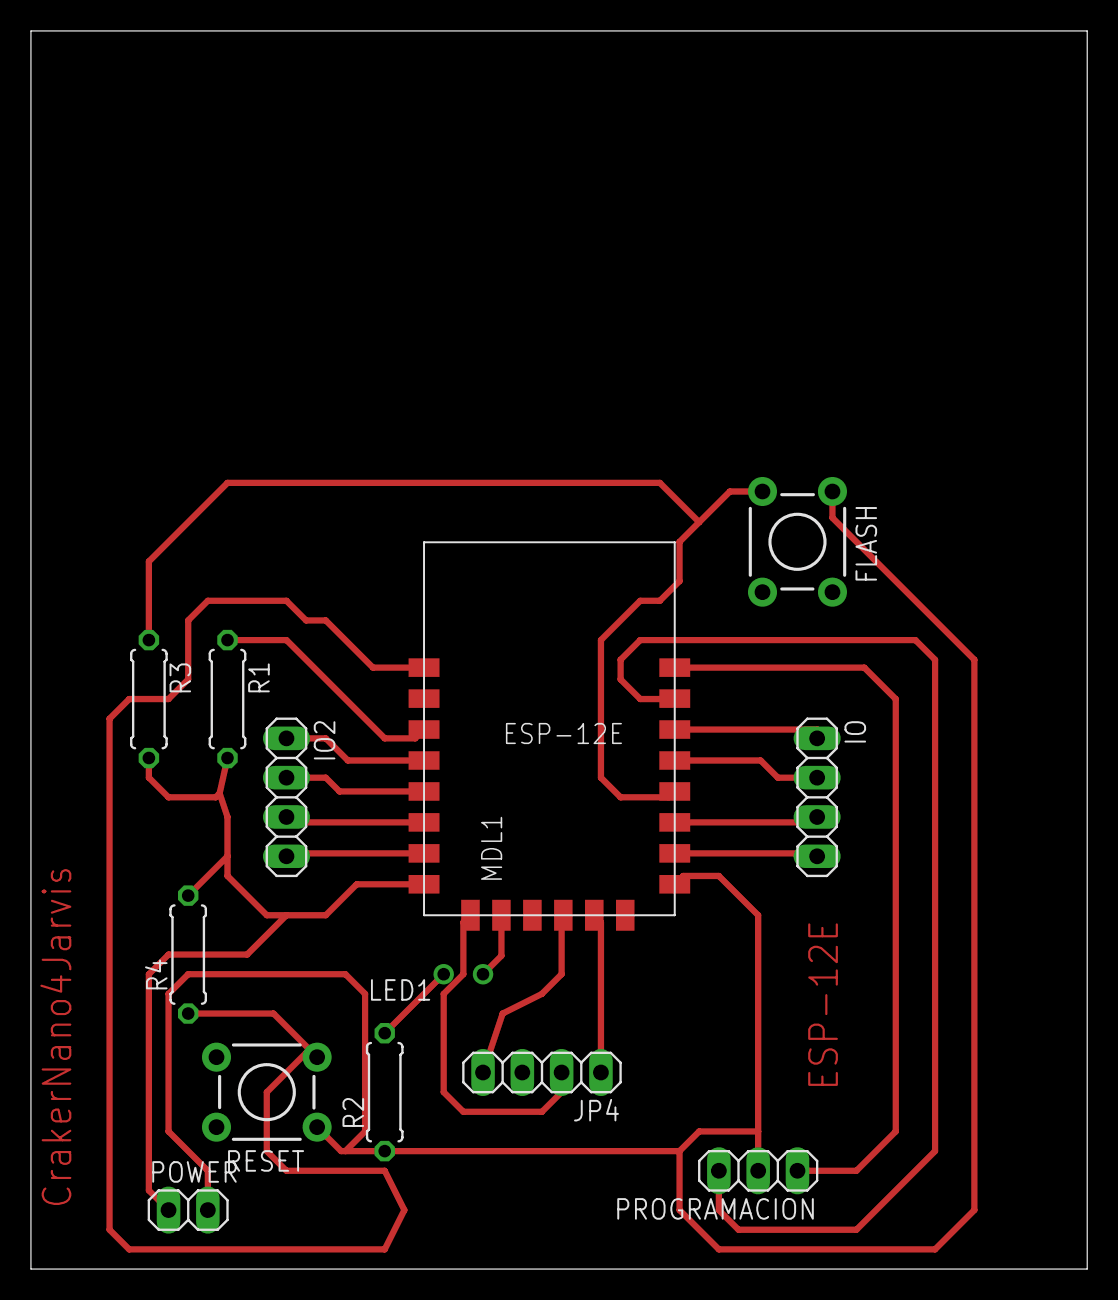
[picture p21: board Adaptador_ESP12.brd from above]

Board: 2 copper layers, 68.2 x 80.0 mm, 13 parts (0 on the bottom side), 20 nets.

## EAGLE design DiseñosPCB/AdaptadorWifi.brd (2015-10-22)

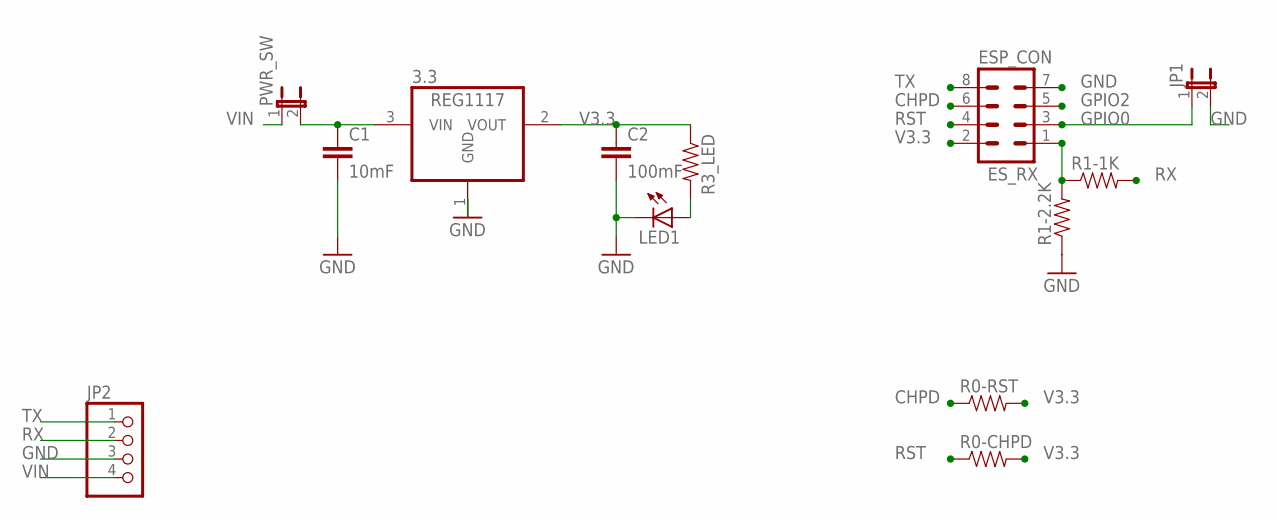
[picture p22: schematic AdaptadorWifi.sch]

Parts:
3.3: REG1117; SOT223
C1: 10mF; 1206
C2: 100mF; 1206
ESP_CON: MA04-2
JP1: JUMPER-2PTH; 1X02
JP2: PINHD-1X4/90; 1X04/90
LED1: LED1206; LED-1206
PWR_SW: JUMPER-2PTH; 1X02
R0-CHPD, R0-RST, R1-1K, R1-2.2K, R3_LED: RESISTOR1206; 1206

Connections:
CHPD: ESP_CON.6, R0-RST.1
ES_RX: ESP_CON.1, R1-1K.1, R1-2.2K.2
GND: 3.3.1 (GND), C1.2, C2.2, ESP_CON.7, JP1.2, JP2.3, LED1.C, R1-2.2K.1
GPIO0: ESP_CON.3, JP1.1
GPIO2: ESP_CON.5
unnamed: LED1.A, R3_LED.2
unnamed: 3.3.3 (VIN), C1.1, PWR_SW.2
RST: ESP_CON.4, R0-CHPD.1
RX: JP2.2, R1-1K.2
TX: ESP_CON.8, JP2.1
V3.3: 3.3.2 (VOUT), C2.1, ESP_CON.2, R0-CHPD.2, R0-RST.2, R3_LED.1
VIN: JP2.4, PWR_SW.1

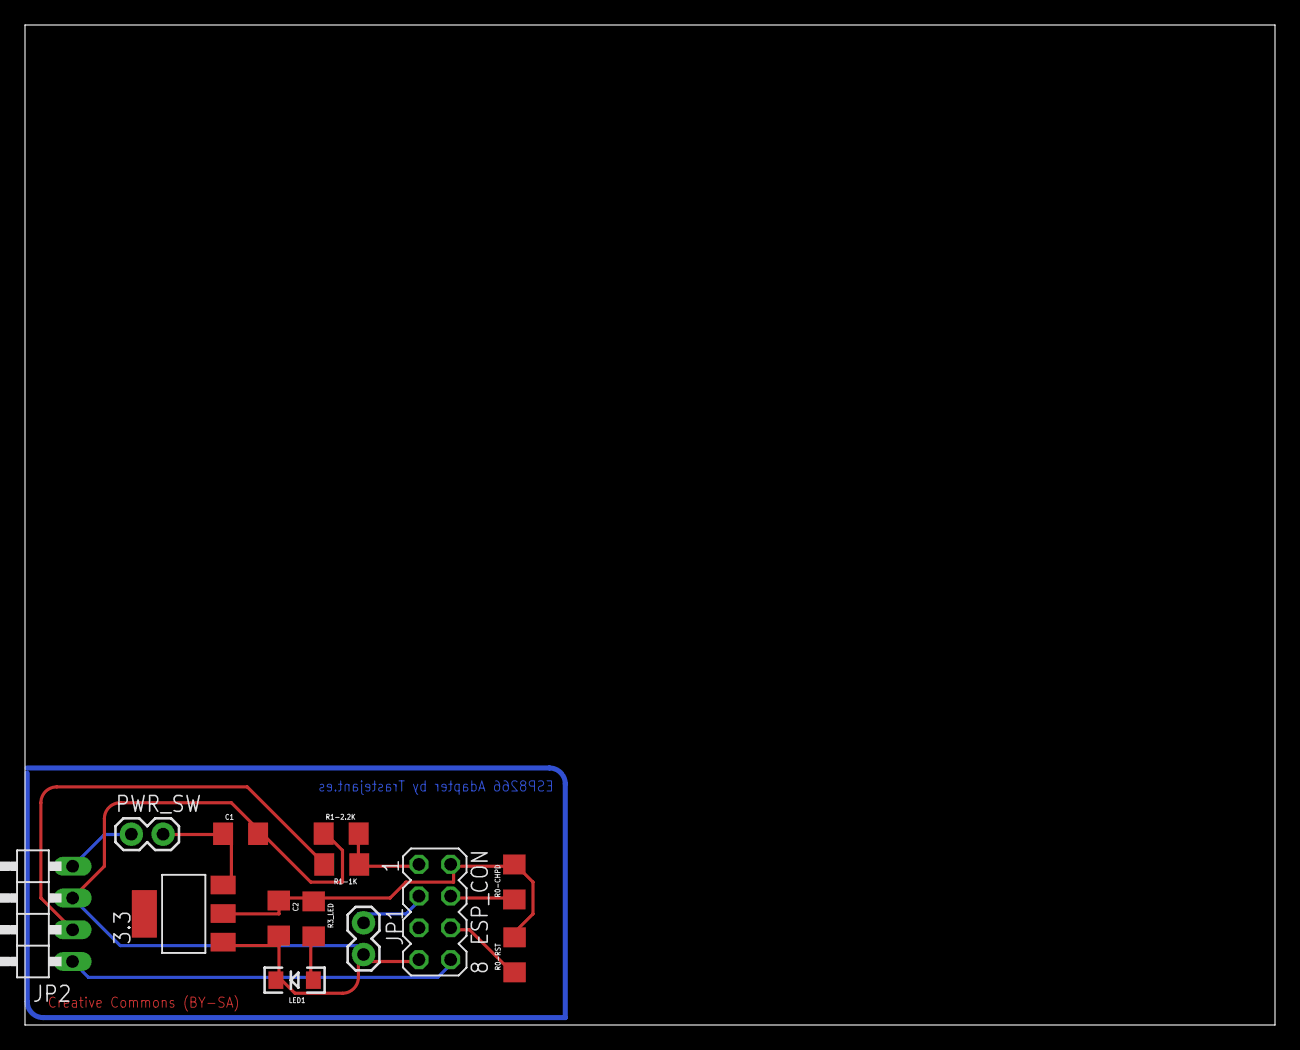
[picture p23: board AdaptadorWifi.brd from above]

Board: 2 copper layers, 100.0 x 80.0 mm, 13 parts (0 on the bottom side), 11 nets.

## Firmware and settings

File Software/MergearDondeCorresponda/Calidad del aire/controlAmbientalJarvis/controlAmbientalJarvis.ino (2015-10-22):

//Version 0.1 del control ambiental de Jarvis.
//Desarrollado por CrakerNano 4 Makespace Madrid

//Lets go!

//llamadas a la librerias
#include <SoftwareSerial.h>
#include <EEPROM.h>
#include <MQ135.h>
#include "DHT.h"
#include <Wire.h>  
#include "RTClib.h"  
#include <SD.h>    
#include <avr/interrupt.h>
#include <avr/sleep.h>
#include "MQ07.h"
#include "alarm.h"
#include "MG811.h"
#include "data.h"
#include "connection.h"
#include "LDR.h"
#include "energy.h"
#include "reboot.h"
#include "jarvisTool.h"
#include "debugger.h"

//CONTANTES-------------------------------------------------------------->
//pines
#define SCLK 13//SCLK del puerto SPI
#define MISO 12//MISO del puerto SPI
#define MOSI 11//MOSI del puerto SPI
#define CS 10//CS del puerto SPI
#define luminoso 9//Led para señales visuales
#define RESETpin 8//Pin para activar el reset de Arduino
#define BTtx 7//TX del puerto serial emulado
#define BTrx 6//RX del puerto serial emulado
#define acustico 5//Altavoz piezolectrico para señales acusticas
#define DHTPIN 4 //Pin del sensor de humedad y temperatura
#define FLAMEpin 3 //Sensor de Llamas
#define WAKEUPpin 2//Pin de interrupcion para despertar al Arduino
#define RX 1//RX del puerto serial y tigger del modo ahorro de energia
#define TX 0//TX del puerto serial
#define MQ135PIN A0 //Pin del sensor NH3, Benceno, Alcohol
#define LDRpin A1 //Pin del sensor de Luz
#define MG811pin A2 //Pin del sensor de CO2
#define MQ07pin A3//Pin del sensor de CO
#define SDA A4//SDA del I2C
#define SCL A5//SCL del I2C

//Limites
#define NH3LIMIT 15000
#define COOLIMIT 15000
#define COLIMIT  15000
#define TEMPMAX 40
#define TEMPMIN 3

//Otros
#define DHTTYPE DHT22 //Configuracion del modelo de sensor DHT22

//Declaracion de Variables 

boolean debuggear;
int tRefresh;


//Declaracion de objetos
SoftwareSerial BT(10, 11); //virtualizamos un puerto serial para la conectividad Bluetooth (RX, TX)
MQ135 mq135 = MQ135(MQ135PIN);//Objeto de la libreria MQ135
DHT dht(DHTPIN, DHTTYPE); //Se inicia una variable que será usada por Arduino para comunicarse con el sensor
MQ07 mq07(MQ07pin);
alarm alarmas(luminoso, acustico);
MG811 mg811(MG811pin);
data jarvisData(CS);
connection link;
LDR ldr(LDRpin);
energy energy(TX,RX);
reboot reboot(RESETpin);
jarvisTool util;
debugger bug(RX,TX);

void setup(){
 
   
   BT.begin(9600);//Inicializacion del puerto serial BT
   BT.println("Serial Port Open"); 
   
   dht.begin(); //Se inicia el sensor de temperatura y humedad
   BT.println("init DHT"); 
   
   Wire.begin();
   BT.println("Real clock init"); 
   
   // inicializacion de las variables
   debuggear = false; 
   Serial.println("init variable");
   
   //Iniciamos el control de interrupciones
   attachInterrupt(WAKEUPpin, wakeup, CHANGE);  
   attachInterrupt(FLAMEpin, llamas, RISING);   
   Serial.println("Attach Interrupt OK");
   
   //Cargamos los valores almacenados en la EEPROM
   tRefresh = 1000;//valor por defecto para el primer arranque
   tRefresh = EEPROM.read(1);
   Serial.println("Load EEPROM values");
   
}

void loop(){
  //Si se ha establecido una conexion Bluetooth, enviamos las lecturas  
  if (BT.available()){
    char c = BT.read();
    jarvisInterface(c);        
  }else{
    //Si no hay conexion, entramos en modo autonomo      
    if(jarvisData.checkExcLimit(getMQ135(dht.readTemperature(),dht.readHumidity()),NH3LIMIT)){alarmas.typeAlarm(1);}//Comprobacion de los niveles de calidad del aire
    if(jarvisData.checkExcLimit(mq07.getCO(),COLIMIT)){alarmas.typeAlarm(2);}//Comprobacion de los niveles de CO
    if(jarvisData.checkExcLimit(mg811.getCOO(),COOLIMIT)){alarmas.typeAlarm(3);} //Comprobacion de los niveles de CO2 
    
    delay(tRefresh);//Tiempo de espera entre refrescos
  }
  
  //Comprobamos si el modo de debuggeo esta activo y si lo esta enviamos todas las lecturas a su funcion para que se muestren
  if(bug.debuggerStatusMode()){bug.debuggerMode(dht.readTemperature(),dht.readHumidity(),getMQ135(dht.readTemperature(),dht.readHumidity()),
                                                mq07.getCO(),mg811.getCOO(),getFlame());}
}


boolean getFlame(){return digitalRead(FLAMEpin);}//Funcion que devuelve la lectura del sensor de llamas.


//Funcion para que devuelve el valor dado por el sensor MQ135
float getMQ135(float t, float h){
  mq135.getCorrectionFactor(t,h);
  float ppm = mq135.getPPM();
  return ppm;
}

void sendArray(float lecturas[]){

  BT.print('#');//Caracter de inicializacion de la cadena    
    for(int i=0; i<sizeof(lecturas)/sizeof(float); i++){
      BT.print(lecturas[i]);
      BT.print('+');    
    }
  BT.print('~'); //caracter de final de cadena
  BT.println();
  delay(10);  
}

void jarvisInterface(int c){
  /*
  0 -> Envia un array con todas las lecturas
  1 -> Activa la alimentacion externa
  2 -> Desactiva la alimentacion externa
  3 -> Devuelve el estado de la alimentacion externa
  4 -> Devuelva la llectura del sensor de llamas
  5 -> devuelve la lectura de la humedad
  6 -> Devuelve la lectura de la temperatura
  7 -> Prueba del zumbador
  8 -> Producen un reset en la placa de Arduino
  9 -> Prueba la alarma visual
  10 -> Volcado de datos de la tarjeta SD
  11 -> Lectura de la calidad del aire
  12 -> Lectura de la cantidad de luz
  13 -> Lectura del sensor de CO 
  14 -> Lectura del sensor de COO
  15 -> Devuelve la hora del modulo
  16 -> Desabilita la placa
  17 -> Coloca el Arduino en Sleep  
  18 -> Activa/Desactiva el modo de debuggeo
  19 -> Devuelve la MAC del modulo
  20 -> Asigna una MAC al modulo
  21 -> Mostrar registro de log
  22 -> Volcado del registro del log
  23 -> Asignar tiempo de refresco
  
  */
  
  switch(c){
    case 0:      
      sendArray(jarvisData.getArrayLecturas(dht.readHumidity(), dht.readTemperature(), ldr.getLight(), getFlame()));
      break;
    case 1:
      energy.enableExternalVcc();
      break;
      
    case 2:
      energy.disableExternalVcc();
      break;
      
    case 3:
      energy.externalVcc();
      break;
      
    case 4:
      BT.println(getFlame());
      break;
      
    case 5:
      BT.println(dht.readHumidity());
      break;
      
    case 6:
      BT.println(dht.readTemperature());
      break;
   
    case 7:
      alarmas.soundAlarm(110);
      break;
      
    case 8:
      reboot.rebootNow();
      break;
      
    case 9:
      alarmas.ligthAlarm(500,500);
      break;
      
    case 10:
      jarvisData.downloadSD();
      break;
      
    case 11:
      getMQ135(dht.readTemperature(),dht.readHumidity());
      break;
      
    case 12:
      BT.print(ldr.getLight());
      BT.print(" (");
      BT.print(ldr.getLightPerCent());
      BT.println(" )");
      break;

    case 13:
      BT.println(mq07.getCO());
      break;
      
    case 14:
      BT.println(mg811.getCOO());
      break;
      
    case 15:
      BT.println(jarvisData.getDate() +" - "+ jarvisData.getTime());
      break;
      
    case 16:
      BT.println("¿Cuanto tiempo deseas mantener la placa desabilitada?(s)");
      int t; 
      t = BT.read();
      t = t * 1000;//Convertimos los segundos en milis
      util.disable(t);
      break;
      
    case 17:
      util.goToSleep();
      break;
      
    case 18:
      if(bug.debuggerStatusMode()){bug.disableDebuggerMode();}else{bug.enableDebuggerMode();}
      break;
   
    case 19:
      BT.println(link.getMAC());
      break;
      
    case 20:
      BT.println("Escriba la MAC que desea asignar al modulo");
      uint8_t mac; 
      mac = BT.read();
      link.setMAC(mac);
      break;
      
    case 21:
      jarvisData.showLog();
      break;
      
    case 22:
      jarvisData.downloadSDlog();
      break;
      
    case 23:
      BT.println("Escriba el tiempo de refresco que desea para el modulo(s)");      
      t = BT.read();
      util.setRefresh(t);
      break;
      
    case 24:
      BT.println("HOLA!");
      break;
      
    default:
      BT.print("Command not found");
      break;    
  }
}

//Funciones llamadas por excepciones.
void llamas(){alarmas.typeAlarm(0);}//Dispara una alarma de tipo fuego si se detectan llamas
void wakeup(){sleep_disable();}//reactiva Arduino

/*ↆↆↆↆↆↆↆↆↆↆↆↆↆↆↆↆↆↆↆↆↆ----------------------------------------- ANOTACIONES --------------------------------------------------------ↆↆↆↆↆↆↆↆↆↆↆↆↆↆↆↆↆↆↆↆↆↆↆ

mq135.getRZero();//El valor devuelto por esta funcion debera ser cargado en MQ135.h -> #define RZERO ____

*/

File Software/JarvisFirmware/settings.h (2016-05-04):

#ifndef FIRMWARESETTINGS
#define FIRMWARESETTINGS

#ifndef ESP8266
#ifndef __AVR_ATmega2560__
//buscar otra etiqueta que descarte el arduino
//Por alguna razon no soy capaz de hacerlo funcionar con #ifdef QT
    #include <QObject>
    typedef quint16 uint16_t;
    typedef quint8 uint8_t;
#endif
#endif

enum jarvisModules
{// el orden de los elementos tiene que coincidir con el de la ventana de configuracion del lado del server
 // Añadir elementos por el final, no reordenarlos.
    unknownModule,
    unConfiguredModule,
    simpleSwitchModule,
    makeSwitchModule,
    airQualityModule,
    simplePowerControlModule,
    advancedPowerControlModule,
    coffeeMakerModule,
    ledNotificationPanelModule,
    ledPanelModule,
    testNodeModule,
    termometroNodeModule,
    doorControlModule
};

struct settingList
{//Configuracion por defecto (Factory)
  //Datos de conexion
  jarvisModules moduleType    = unConfiguredModule;
  char          id[20]          = "Configureme";
  char          wifiESSID[25]   = "ConfigureMe";
  char          wifiPasswd[25]  = "configureme";
  bool          wifiAPMode      = true;
  char          remoteHost[25]  = "Jarvis";
  uint16_t      remotePort      = 31416;
  uint16_t      localPort       = 31416;
  uint16_t      updateInterval  = 25;

  int8_t            alivePin            =   2;
  int8_t            piezoPin            =  -1;
  int8_t            ledStripPin         =  13;
  float             ledStripBrightness  =   0.1f;
  uint16_t          ledCount            =   3;
  uint8_t           ledMatrixFirstLed   =   0;
  uint8_t           ledMatrixCols       =   16;
  uint8_t           ledMatrixRows       =   16;
  bool              ledMatrixZigZag     =   true;
  bool              ledMatrixMirror     =   false;


  int8_t           buttonPins[10]      = {  16,  -1,  -1,  -1,  -1,  -1,  -1,  -1,  -1,  -1};
  int8_t           tempSensorPins[10]  = {   5,  -1,  -1,  -1,  -1,  -1,  -1,  -1,  -1,  -1};
  int8_t           relaypins[10]       = {  12,  -1,  -1,  -1,  -1,  -1,  -1,  -1,  -1,  -1};

  uint16_t          magicNumber            = 31415;

  /**
Tabla de correspondencia de pines nodemcu arduino
0 [*]  GPIO16  
1  GPIO5 
2  GPIO4
3  GPIO0
4  GPIO2
5  GPIO14 (SPI CLK)    
6  GPIO12 (SPI MISO)   
7  GPIO13 (SPI MOSI)   
8  GPIO15 (SPI CS)
9  GPIO3 (UART RX)
10 GPIO1 (UART TX)
11 GPIO9
12 GPIO10
A0 17
**/  

//Pineado por defecto de los nodos ESP8266
//    int   ledStripPin            =  4; //makeswitch
//    int   ledStripPin            =  13; // LedPanel /coffeemaker
//    DHT    makeswitch  5
//    dht MMMtermimetro  2


};

#endif

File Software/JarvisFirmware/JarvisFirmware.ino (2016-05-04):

// Arduino IDE WTF #1 hay que hacer el include de las librerias en el .ino! No vale si las haces en el .c
#include <Adafruit_NeoPixel.h>
#include <EEPROM.h>
#include <Wire.h>
#include <DHT.h>
#include <RTClib.h>

#ifdef ESP8266
  #include <ESP8266WiFi.h>
  #include <ESP8266WebServer.h>
  #include <ESP8266mDNS.h>
  #include <ESP8266HTTPUpdateServer.h>
  #include <FS.h>
#endif


//Arduino IDE WTF#2
//Por aguna razon la siguiente libreria que es para poder usar la clase vector con el arduino hace crujir la compilacion en el ESP
//Aunque la he probado a poner bajo un ifndef se sigue activando la libreria y fallando para el esp.
//Lo unico que funciona es comentarla para compilar en ESP. 
//  
//
#ifndef ESP8266
  //#include <MemoryFree.h>
  //#include <StandardCplusplus.h>  //Comentar para compilar en el ESP//Descomentar en arduino!!!!!!!!!!!!
#else
extern "C" {
#include "user_interface.h"
}
#endif

//Magia negra con ifdefs

//#define DEBUG_PROTOCOL
//#define EXTRA_CARRIAGE_RETURN //añade un retorno de carro a los paquetes de protocolo para leerlos mejor

#ifdef ESP8266
    #define DEBUG_STRINGS //Se esta usando?
    #define VERBOSE_DEBUG
    #define BIG_FLASH
#endif

uint16_t updateInterval = 25;


#include "helpers.h"
#include "jarvisNode.h"
#include "simplePowerControl.h"
#include "MakeSwitch.h"
#include "coffeeMaker.h"
#include "ledPanelNode.h"
#include "lednotificationpanel.h"
#include "testNode.h"
#include "termometroNode.h"
#include "doorcontrolnode.h"


jarvisNode* node;
EEPROMStorage EEPROMSettings;

void setup() 
{
    Serial.begin(115200);
    //EEPROMSettings.clearEEPROM();
    EEPROMSettings.reload();
    node = 0;
    jarvisModules type = EEPROMSettings.settings().moduleType;

    if      (type == unConfiguredModule)
    {
        node = new jarvisNode(&EEPROMSettings);
    }
    else if(type == simpleSwitchModule)
    {
        node = new simpleSwitch(&EEPROMSettings);
    }else if(type == makeSwitchModule)
    {
        node = new makeSwitch(&EEPROMSettings);
    }else if(type == airQualityModule)
    {

    }else if(type == simplePowerControlModule)
    {
        node = new simplePowerControl(&EEPROMSettings);
    }else if(type == advancedPowerControlModule)
    {

    }else if(type == coffeeMakerModule)
    {
        node = new coffeeMaker(&EEPROMSettings);
    }else if(type == ledPanelModule)
    {
        node = new ledPanelNode(&EEPROMSettings);
    }else if(type == ledNotificationPanelModule)
    {
        node = new ledNotificationPanelNode(&EEPROMSettings);
    }else if(type == testNodeModule){
        node = new testNode(&EEPROMSettings);
    }else if(type == termometroNodeModule){
        node = new termometroNode(&EEPROMSettings);
    }else if(type == doorControlModule){
        node = new doorControlNode(&EEPROMSettings);
    }

    if(node == 0)
        node = new jarvisNode(&EEPROMSettings);


    node->setup();
}


#ifndef ESP8266
ISR(TIMER0_COMPA_vect){//interrupcion 0.
    //if(int0Pointer) int0Pointer();
    //mySwitch.currentSensor().isrRead();
}
#endif

void loop() {
  node->update();
}

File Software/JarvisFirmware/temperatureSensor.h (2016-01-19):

#ifndef TEMPERATURESENSOR_H
#define TEMPERATURESENSOR_H

#include "nodeComponent.h"

class dhtTemperatureSensor : public nodeComponent
{
public:
  dhtTemperatureSensor(DHT* dhts) : nodeComponent(0), m_dht(dhts)
  {
    m_id = F("dhtTemp");
    m_actions.push_back(A_READ_DATA);
    m_capableEvents.push_back(E_DATA_READ);
  }

  bool     canRead()  {return true;}


  virtual float      readData()
  {
    if(!m_enabled){return 0;} // si el dispositivo no esta habilitado ni se intenta acceder al hardware
    return m_dht->readTemperature();
  }

protected:
  DHT* m_dht;

};

class dhtHumiditySensor : public nodeComponent
{
public:
  dhtHumiditySensor(DHT* dhts) : nodeComponent(0), m_dht(dhts)
  {
    m_id = F("dhtHumid");
    m_actions.push_back(A_READ_DATA);
    m_capableEvents.push_back(E_DATA_READ);
  }

  bool     canRead()  {return true;}

  virtual float      readData()
  {
    if(!m_enabled){return 0;}
    return m_dht->readHumidity();
  }

protected:
  DHT* m_dht;
};


/////
//// Pasan cosas raras al instanciar dos veces el DHT, le he creado su propio objeto y a los dos objetos sensor(temp y humedad) se les pasa el puntero
////
////

class dhtSensor
{
public:
  dhtSensor(int pin = -1) :
  m_dht(pin,DHT22), m_temp(&m_dht), m_humid(&m_dht) {}

  nodeComponent* temperatureSensor() {return &m_temp;}
  nodeComponent* humiditySensor()    {return &m_humid;}

protected:
  DHT m_dht;
  dhtTemperatureSensor  m_temp;
  dhtHumiditySensor     m_humid;

};

class ntc100kTemperatureSensor : public nodeComponent
{
public:
  ntc100kTemperatureSensor(int pin) : nodeComponent(pin)
  {
    m_id = F("ntcTemp");
    m_actions.push_back(A_READ_RAW);
    m_capableEvents.push_back(E_RAW_READ);
    m_actions.push_back(A_READ_DATA);
    m_capableEvents.push_back(E_DATA_READ);
  }

  void setup()
  {

  }

  bool isValid()        {return true;}
  bool     canRead()    {return true;}

  uint16_t readRaw()
  {
      if(!m_enabled){return 0;}
      return analogRead(m_pin);
  }

  virtual float      readData()
  {
    if(!m_enabled){return 0;} // si el dispositivo no esta habilitado ni se intenta acceder al hardware
    return convertRead(readRaw());
  }


  static float convertRead(uint16_t raw)
  {

    #define THERMISTORNOMINAL 80000
    // temp. for nominal resistance (almost always 25 C)
    #define TEMPERATURENOMINAL 25
    // how many samples to take and average, more takes longer
    // but is more 'smooth'
    //#define NUMSAMPLES 5
    // The beta coefficient of the thermistor (usually 3000-4000)
    #define BCOEFFICIENT 3950
    // the value of the 'other' resistor
    #define SERIESRESISTOR 160000

      float average = raw;
      // convert the value to resistance
      average = 1023 / average - 1;
      average = SERIESRESISTOR / average;
      Serial.print("Thermistor resistance ");
      Serial.println(average);

      float steinhart;
      steinhart = average / THERMISTORNOMINAL;     // (R/Ro)
      steinhart = log(steinhart);                  // ln(R/Ro)
      steinhart /= BCOEFFICIENT;                   // 1/B * ln(R/Ro)
      steinhart += 1.0 / (TEMPERATURENOMINAL + 273.15); // + (1/To)
      steinhart = 1.0 / steinhart;                 // Invert
      steinhart -= 273.15;                         // convert to C

      Serial.print("Temperature ");
      Serial.print(steinhart);
      Serial.println(" *C");
      return steinhart;
  }

protected:


};



class tmp36Sensor : public nodeComponent
{
public:
  tmp36Sensor(int pin) : nodeComponent(pin)
  {
    m_id = F("tmp36");
    m_actions.push_back(A_READ_RAW);
    m_capableEvents.push_back(E_RAW_READ);
    m_actions.push_back(A_READ_DATA);
    m_capableEvents.push_back(E_DATA_READ);
  }

  void setup()
  {
    pinMode(m_pin, INPUT);
  }

  bool isValid()        {return true;}
  bool     canRead()    {return true;}

  uint16_t readRaw()
  {
      if(!m_enabled){return 0;}
      return analogRead(m_pin);
  }

  virtual float      readData()
  {
    if(!m_enabled){return 0;} // si el dispositivo no esta habilitado ni se intenta acceder al hardware
    uint16_t value = readRaw();
    uint8_t iterations = 10;// 64 es lo maximo que un uint16 puede albergar de forma segura para hacer la media (si todos son 1024...1024*64 = 16bits)
    for(int i = 0 ; i < iterations ; i++)
    {
        value += readRaw();
    }
    return convertRead(value/iterations);
  }


  static float convertRead(uint16_t raw)
  {
      //Serial.print(raw); Serial.println(" raw");
      // converting that reading to voltage, for 3.3v arduino use 3.3
      float voltage = raw * 3.3;
      voltage /= 1024.0;
      float temperatureC = (voltage - 0.5) * 100 ;  //converting from 10 mv per degree wit 500 mV offset
                                                    //to degrees ((voltage - 500mV) times 100)

      //Serial.print(temperatureC); Serial.println(" degrees C");
      // now convert to Fahrenheit
      //float temperatureF = (temperatureC * 9.0 / 5.0) + 32.0;
      //Serial.print(temperatureF); Serial.println(" degrees F");

      return temperatureC;
  }

protected:


};


#endif // TEMPERATURESENSOR_H

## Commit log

2015-05-18 Primera idea para el diseño del modulo "MakeSwitch"
    [MakeSwitch.fcstd]
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2015-06-03 Tapa para los modulos de control de enchufes con conmutador
    [cubre-modulos.fcstd, cubre-modulos.stl]
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2015-06-12 Rectificadas tolerancias del cubre-modulos para enchufes
    [cubre-modulos.fcstd, cubre-modulos.stl]
2015-08-03 Carcasa para el modulo de calidad del aire
    [carcasa_modulo.fcstd, carcasa_modulo.stl, cubre-modulos.fcstd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]
2015-08-22 Adaptador para los ESP2866
    [AdaptadorWifi.brd, AdaptadorWifi.sch]
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2015-10-04 Inicio del modulo de comunicaciones. codigo c y pruebas en lua para el puente serie
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2015-10-13 arreglado el bug del puerto de comunicaciones.
2015-10-14 Primeras pruebas con el interface web en el esp Modulo de comunicacion esclavo
2015-10-18 refactorizacion del parseador para poder reutilizarlo tanto en los modulos como en el cerebro
2015-10-22 refactorizacion del codigo.
    despues de la cagada de borrar la carpeta de trabajo sin haber actualizado le repo en dos dias se ha refactorizado el codigo para integrarlo todo en la clase jarvisModule.
    En el camino he reimplementado gran parte de los cambios que se han perdido, aunque todavia queda bastante para dejarlo en el estado que estaba esta mañana.
2015-11-27 Reorganizacion del repo
    [AdaptadorWifi.brd, AdaptadorWifi.sch, MakeSwitch.fcstd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]
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2015-11-29 MakeSwitch V2
    [base.obj, carcasa-dual.amf, carcasa_make-amarillo (repaired).stl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]
2015-12-01 pequeñas correcciones
    [carcasa-sinlgeColor (repaired).stl, piloto.obj]
2015-12-04 Carcasa MakeSwitch cortada a la mitad
    [bottom-a (repaired).stl, bottom-a.obj, bottom-b (repaired).stl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]
2015-12-06 Jarvis firmware 0.6
    Trabajos variados en el firmware para la implementacion en el primer modulo.
    -Movida toda la parte de parseo de protocolo a la clase communicationModule, desde el parseo se llaman a interfaces virtuales que implementa el jarvisModule.
    -Creados interfaces para sensores y actuadores, que pueden emitir eventos y recibir acciones.
    -Ahora el modulo de jarvis contiene arrays(vectores) de sensores y actuadores, la idea es que los 'modulos finales lo hereden y añadan sus sensores y actuadores a los arrays de sensores/actuadores pa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
    (Implementacion del makeswitch como ejemplo)
    -Reformado el codigo de los led, y hecho sensor.
    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
    [caja.stl, protecciones-mesaHerramientas.fcstd]
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2015-12-11 Refactorizacion del codigo: -Sensores y actuadores unidos en una unica interfaz nodeComponent -Mejoras en los objetos de los led -Creado nuevo tipo de objeto para controlar la cafetera -Limpieza por 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
    Vuelve a compilar para el arduino Nano!! eso si, con calzador(99%)
2015-12-14 Aplicacion de test para los Nodos
    - Mejoras de codigo por aqui y por alla para hacer la integracion.
    Funciones:
    - Señalizacion de los eventos.
    - Visualizacion de las acciones, y posibilidad de actuar sobre las mismas.
    - Graficas con las lecturas de los sensores
    - Consola
2015-12-28 Mejoras aqui y alla:
    (cambios de los que me acuerdo)
    Jarvis Firmware
    - Terminados de implementar los metodos de lectura de componentes a traves de interfaz
    Cambios en la forma de lectura, ahora se pueden consultar los sensores a traves de las acciones, generandose un evento de lectura.
    Paralelamente se puede activar un modo de lectura periodica para consultar los sensores a alta velocidad sin riesgo de petar el buffer de entrada con las solicitudes.
    -Nuevo tipo de nodo ledPanel para controlar una matriz led de 16*16
    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
2016-01-03 Implementacion para el reloj de tiempo real PCB adaptadores para los ESP12E
    [Adaptador_ESP12.brd, Adaptador_ESP12.sch]
2016-01-10 -Ampliación del modulo coffeeMaker
    Ahora puede hacer cae :)
    -Mejoras en el manejo de los leds
    Mas efectos.
    -Cambio en la estructura del jarvisNode, ahora el nodo hereda tambien un nodeComponent.
    Jugando con las implementaciones de los nodos estaba econtrando problemas con la gestion de eventos, pues al final el nodo acaba funcionando como un 'supercomponente de componentes' que necesita acceder a varios de los componentes que lo integran para hacer acciones de 'alto nivel';
    p.e.: el modulo de la cafetera para reaccionar la accion "MAKE_COFFEE" necesita poder leer la temperatura del sensor y operar sobre el rele(ambos componentes aparte).
    Con el ultimo cambio la gestion de los eve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
    [jarvisProtocol.h, settings.h]
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2016-01-14 Mejoras en el modulo coffeeMaker e implementacion dummy de un termistor ntc100k
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2016-01-17 modificado el patron de gitignore para que ignore todos los directorios que empiecen con build-
2016-01-17 Mejoras varias cliente/servidor: -validacion del cliente y el servidor, ahora ambos se saludan para verificar que estan hablando con lo que esperan hablar. -añadido sensor de temperatura tmp36 -Reorg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
2016-01-20 Pineado correcto para los modulos de termometro
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2016-01-22 Mejoras en la matriz led.
    Ahora contiene un array de dos dimensiones con la geometria del display
    m_matrix[x[y]
2016-01-22 Comentado #define que puede dar problemas.
    Para que el qt creator haga completado de codigo en la parte especifica del esp en el communication.h uso un define para habilitar la etiqueta ,la ultima vez me la deje puesta y podria hacer fallar la compilacion para arduino
2016-01-24 Añadido actualizador web y repondedor mdns
    Ambos estan integrados en la ultima version de la integracion de arduino.
    El webflash funciona el 50% de las veces... el 25% te deja el esp 'brickeado' y hay que reprogramar por serie
2016-01-26 Mejoras para el panel de leds nodo/cliente/testapp.
    Cambios en el metodo de transmision, nueva accion A_DISPLAY que manda los pixeles a la pantalla en formato x,y,r,g,b .... nx,ny,nr,ng,nb
    Mejoras en la ventana de seleccion de imagen
    etc....
2016-01-31 Informar de la ip al conectarse
    Ahora se escupe la direccion ip despues de conectar, asi no hay que reiniciar para saber la ip.
    Ahora la red de autoconfiguracion lleva el id del chip en el nombre de la red para evitar confusion entre varios dispositivos.
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2016-02-22 Mejoras variadas en el firmware/server (Incluido pero no limitado a ....) Firmware: - bugs del piezo - Mejoras en los leds, ahora responden a la accion DIMM para establecer su brillo(independiente de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
    Server
    - Ventanas varias para el reproductor rtttl y configuracion del wifi del nodo
    - Mejoras en el mecanismo de recoñexion de los nodos
    [jarvisProtocol.h]
2016-02-26 -Mejoras en el mecanismo de conexion accion-evento server-side -Arreglado el pineado el ledPanelNode
    [JarvisFirmware.ino, settings.h, ws2812led.h]
2016-03-06 pequeño fix de operadores
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2016-03-24 actualizacion del repo. Mejoras en el interfaz grafico; Poder borrar los nodos para forzar la reconexion/reconfiguracion. Ahora mismo tiene un bug cuando se activa una regla que tenga como destino el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
2016-03-25 Fixes variados -Posible race-condition en los dispositivos con muchos leds en los que era posible que la conn wifi se estableciera antes de terminar de encender todos los leds. -Desregistrar los comp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
    [settings.h, ws2812led.h]
2016-03-26 -Terminada ventana de configuracion de reglas -retoques en los widgets -arreglo de bugs
    [JarvisFirmware.ino]
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2016-05-04 Mejoras en la carga de imagenes. Aplicacion separada para generar/visualizar los archivos de imagen.
    Se arrastran un par de bugs en la visualizacion del panel y en la app de visualizacion.
    [main.cpp, ws2812led.h]
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

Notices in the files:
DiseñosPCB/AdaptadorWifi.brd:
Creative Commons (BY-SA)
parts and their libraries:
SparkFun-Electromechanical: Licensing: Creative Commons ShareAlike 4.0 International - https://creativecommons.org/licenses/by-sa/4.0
